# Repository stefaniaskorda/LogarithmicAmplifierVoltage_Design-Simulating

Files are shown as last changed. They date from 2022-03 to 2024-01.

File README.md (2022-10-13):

# microelectronics-and-packaging

Logarithmic Amplifier Project for the course Microelectronics&amp;Packaging

This project implemented for the course Microelectronics and Packaging at 7th semester in Electrical and Computer Engineering School of National Technical University of Athens and was graded 10/10.

## 0.Context: The circuit we have chosen is known as a logarithmic amplifier voltage, as the output voltage which produces, it is proportional to its neper logarithmic input voltage.
the circuit consists of a voltage source, a resistor, an opamp and a bjt transistor. In particular, we chose as an opamp the LM714, npn: 2N2222 and R=10KΩ. The schematic is shown below:

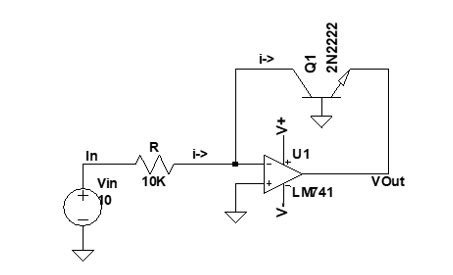
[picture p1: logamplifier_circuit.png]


## 1.Simulation of the circuit 
We ran a dc sweep simulation in LTspice to make sure our circuit is working properly. Spice doesn't have the LM741 model, so we had to import it. As we saw in the datasheet of LM714, it has a source voltage of +/-15v, so we put V+=15-1=14V and v-=-14v, as positive and negative supply voltage respectively. We set the dc sweep for Vin from 0.1 to 10v to see the VOUT curve as a function of the input voltage.

## 2.Designing PCB
In the specific part of the report, the schematic design of the circuit arrangement we have chosen, the voltage logarithmer, as well as the design of the board for the specific arrangement will be made through the EAGLE design program.

### The diagram using Eagle:
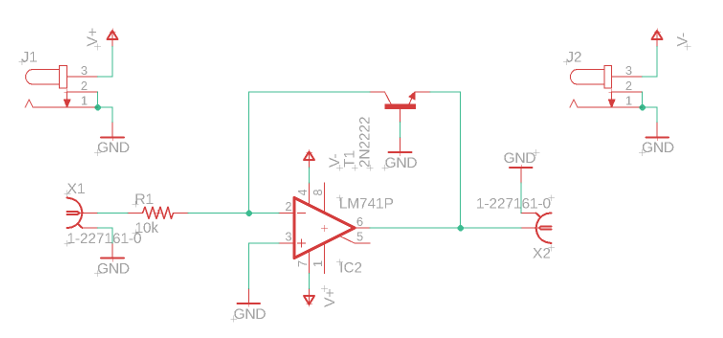
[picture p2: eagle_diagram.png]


### The final PCB design:
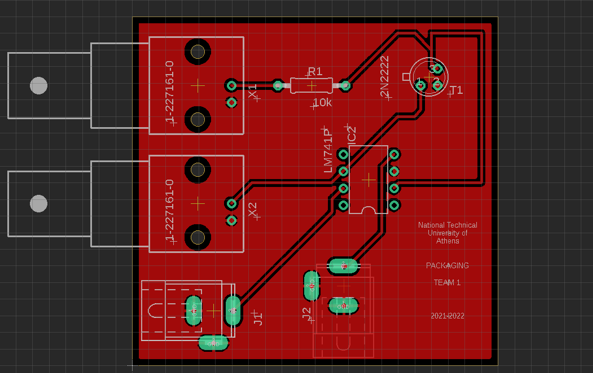
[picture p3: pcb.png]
## 3.Implementation of Heatsinks

## 4. Design of Heatsinks
Fusion360 was used as CAD program for the design of Heatsinks for the bjt (2n2222) and for the opamp (lm741).
Below are the designs:

### opamp lm741
* 1st Heatsink
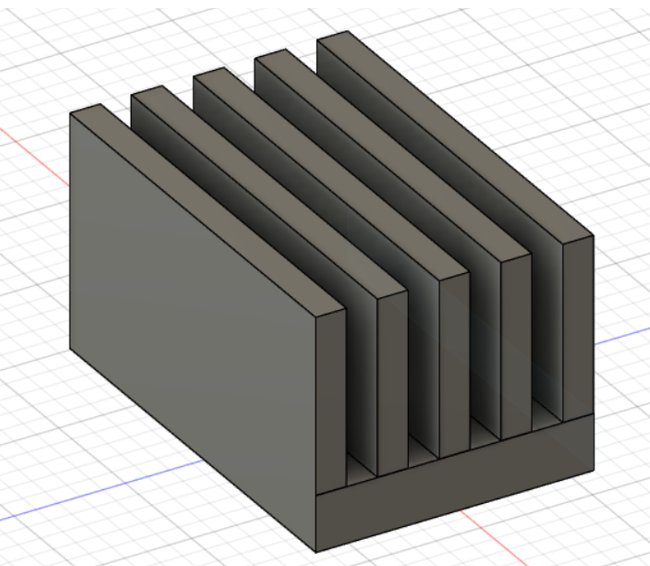
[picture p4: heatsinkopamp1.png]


* 2nd Heatsink
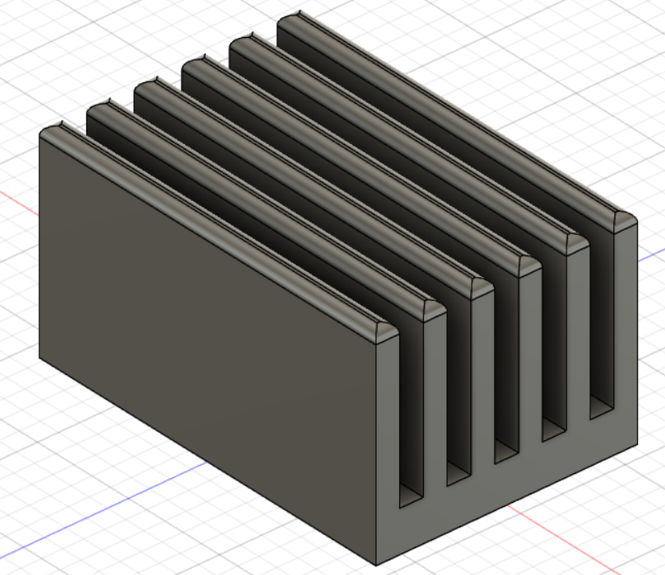
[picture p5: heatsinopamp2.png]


* 3rd Heatsink
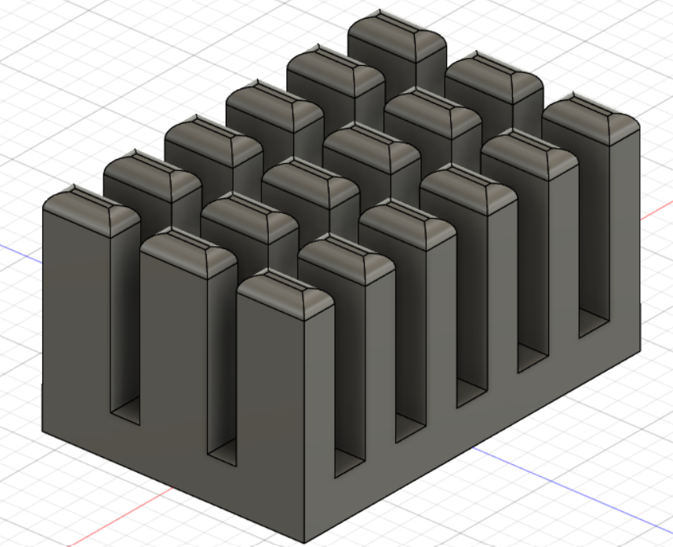
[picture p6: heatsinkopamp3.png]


* 4rth Heatsink
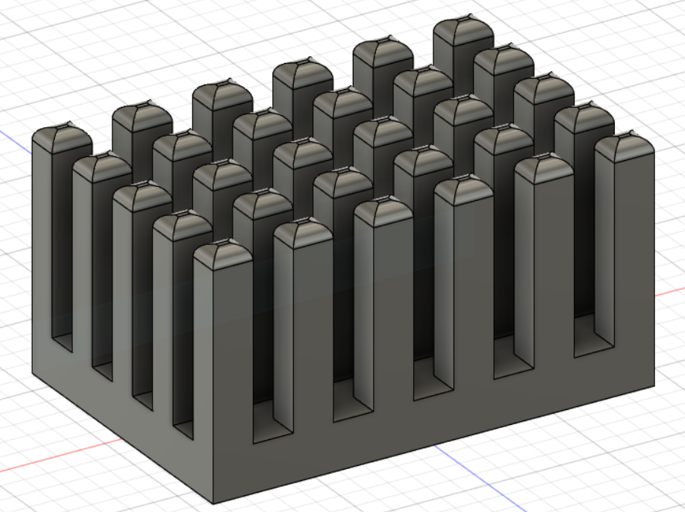
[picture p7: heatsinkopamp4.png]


### bjt 2n2222

* 1st Heatsink
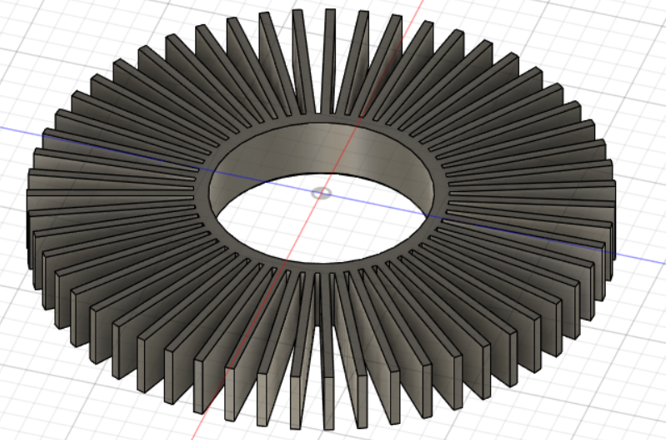
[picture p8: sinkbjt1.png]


* 2nd Heatsink
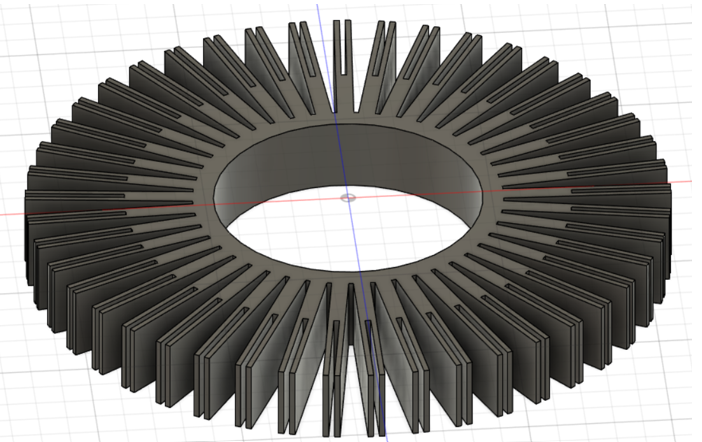
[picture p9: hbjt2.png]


## 5.Thermal Analysis

The thermal analysis of the board will be carried out to observe the ability of the heatsinks to fulfill their role, but also to make a comparison between them in terms of the cooling capacity of each one.

To be able to carry out the analysis we will use the online program SimScale.
Before we proceed with the simulations, the following fields in SimScale are required to be filled out.
More specifically, what needed to be filled in or changed in the simulation environment is included in the list below.
* Element Materials:
* LM741 (OPAMP): The OPAMP body (the polymer) is Epoxy. Its pins are made of lead.
* 2N2222 (NPN): The body of the bipolar is tin (Tin) . Its pins are made of lead.
* Heat sinks: All heat sinks are made of aluminum.

### opamp lm741
* 1st Heatsink
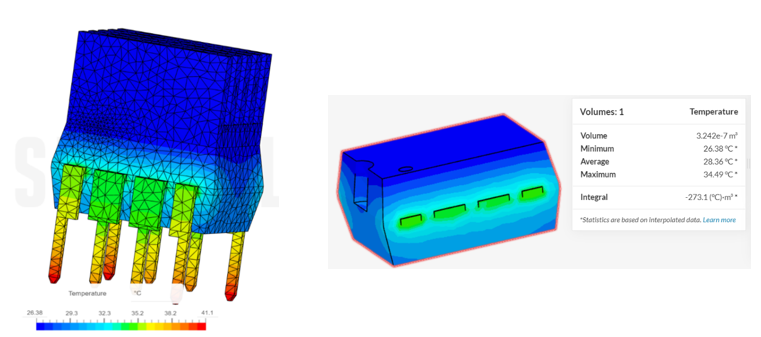
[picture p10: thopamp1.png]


* 2nd Heatsink
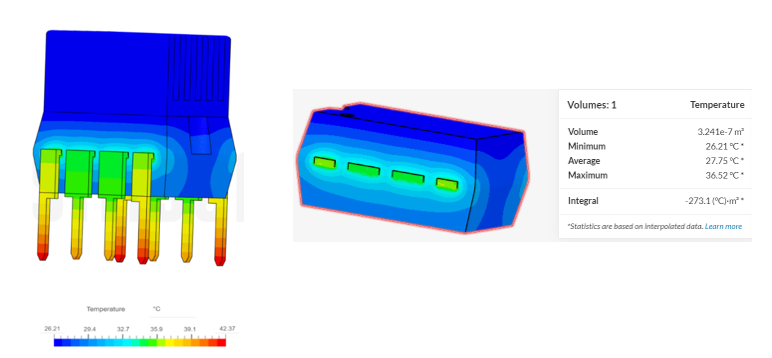
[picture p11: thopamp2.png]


* 3rd Heatsink
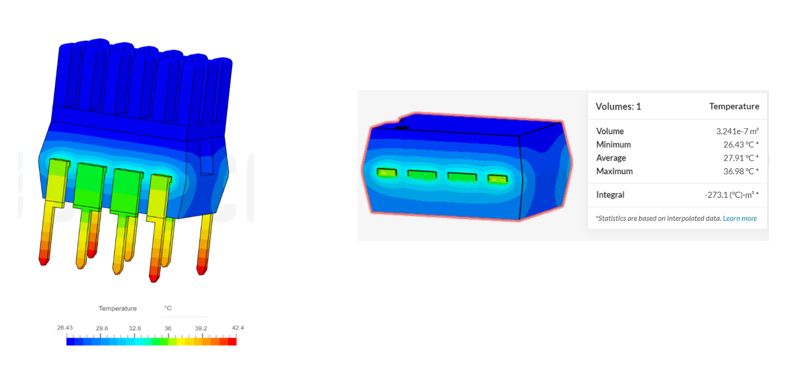
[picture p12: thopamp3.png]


* 4rth Heatsink
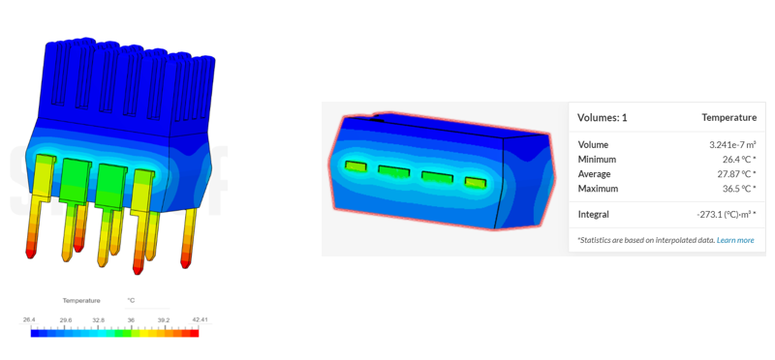
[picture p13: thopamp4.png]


### bjt 2n2222

* 1st Heatsink
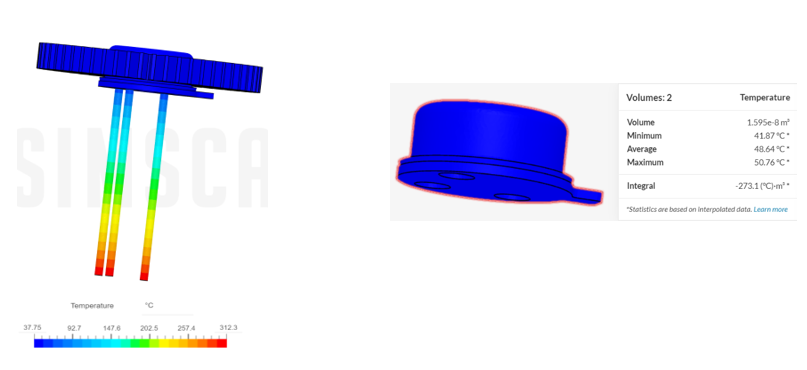
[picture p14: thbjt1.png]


* 2nd Heatsink
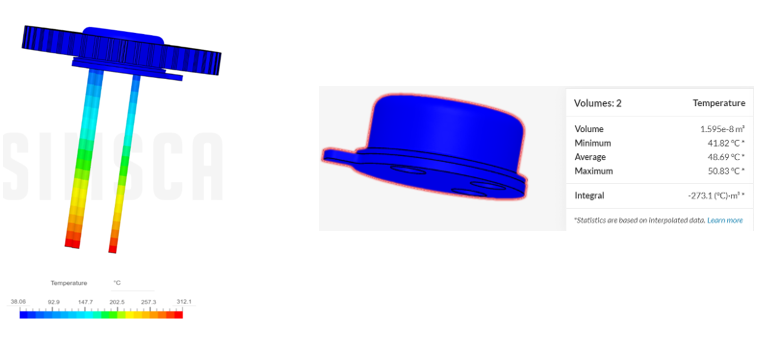
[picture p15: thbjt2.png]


## 6. Conclusion

For the opamp lm741 the 2nd Heatsink approoved as the best one and for the bjt 2n2222 the 1st one was the best as heatsinks.

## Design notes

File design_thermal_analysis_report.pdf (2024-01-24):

## ΕΘΝΙΚΟ ΜΕΤΣΟΒΙΟ ΠΟΛΥΤΕΧΝΕΙΟ

ΣΧΟΛΗ ΗΛΕΚΤΡΟΛΟΓΩΝ ΜΗΧΑΝΙΚΩΝ ΚΑΙ ΜΗΧΑΝΙΚΩΝ ΥΠΟΛΟΓΙΣΤΩΝ

ΚΑΤΕΥΘΥΝΣΗ ΗΛΕΚΤΡΟΝΙΚΗΣ ΚΑΙ ΣΥΣΤΗΜΑΤΩΝ

## Εξαμηνιαία Εργασία

## στο μάθημα «Μικροηλεκτρονική και Τεχνικές Συσκευασίας»

των φοιτητών

Λυμπεράκης Γεώργιος, Α.Μ: 03118881 Σκόρδα Στεφανία, Α.Μ: 03118852 Καγιάρα Νίκη, Α.Μ: 03118031 Ταξείδη Άρτεμις, Α.Μ:03116044

Διδάσκοντες: Χριστοφόρου Ευάγγελος

Αθήνα, Ιανουάριος 2022

Εισαγωγή – Περιγραφή Κυκλώματος

Το κύκλωμα που επιλέξαμε για τις προσομοιώσεις είναι γνωστό ως λογαριθμιστής τάσης, καθώς η τάση εξόδου που παράγει είναι ανάλογη του νεπέριου λογάριθμου της τάσης εισόδου του.

Το κύκλωμα αποτελείται από μια πηγή τάσης ,μια αντίσταση ,έναν opamp και ένα bjt transistor.Συγκεκριμένα επιλέξαμε ως opamp τον LM714, npn:2N2222 και R=10ΚΩ.Το σχηματικό φαίνεται παρακάτω:

Ακολουθεί η απόδειξη πως το κύκλωμα λειτουργεί ως λογαριθμιστής τάσης.

Ως γνωστόν ,σε έναν τελεστικό ενισχυτή ισχύει ),όπου Α το κέρδος του,V+,V- η τάση στον θετικό και τον αρνητικό ακροδέκτη εισόδου αντίστοιχα . Όμως στον ιδανικό opamp VOUT/A=0 η αντίσταση εισόδου του τελεστικού είναι και αυτή άπειρη, οπότε δεν περνάει ποτέ ρεύμα από μέσα του καθώς

Ι+=Ι-=0.

Οπότε το ρεύμα περνάει όλο από την αρνητική ανάδραση, συνεπώς από το bjt.Άρα ισχύει για το ρεύμα του συλλέκτη IC = I/R

Όμως το ρεύμα συλλέκτη ενός bjt δίνεται από τον τύπο: IC = IS ∗ (e

VCE
VT − 1),όπου ls
το ρεύμα κορεσμού και vt η θερμική τάση του bjt(σύμφωνα με το datasheet του 2Ν2222 :IS=1.16*10⁻¹⁴A και vt=25.28). Οπότε συνεπάγεται ότι: :

VIN
R

= IS ∗
(e

vce
vt − 1) ≅ IS ∗ e
VCE/vt καθώς e

vce/vt ≫ 1

vce = v− − vout = −vout ⇒ ln (

VIN
R

) = ln(IS) ∗ (−

vout
vt ) ⇒ vout = −vt ∗ ln(

vin
R ∗ IS)

Μια αναμενόμενη τιμή τάσης εξόδου σύμφωνα με τον παραπάνω τύπο είναι :για vin=10V:

Vout=0.025*ln(10/10^3*1.16*10^-14)=592.2mV

Στην συνέχεια εκτελέσαμε στο LTspice μια dc sweep προσομοίωση για να βεβαιωθούμε ότι το κύκλωμα μας λειτουργάει σωστά. Το spice δεν διαθέτει το μοντέλο του LM741,οποτε έπρεπε να το εισάγουμε εμείς. Όπως είδαμε στο datasheet του LM714,εχει τάση κόρου +/-15v,οπότε βάζουμε V+=15-1=14V και v-=-14v,ως θετική και αρνητική τάση τροφοδοσίας αντίστοιχα. Ορίσαμε το dc sweep για την Vin από 0.1 έως 10v για να δούμε την καμπύλη VOUT συναρτήσει της τάσης εισόδου .Παρακάτω φαίνεται το κύκλωμα έτοιμο για προσομοίωση.

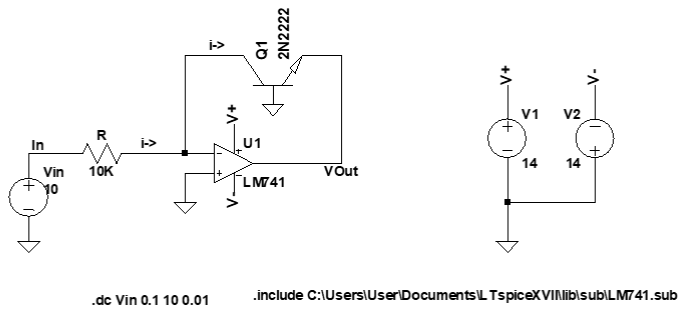
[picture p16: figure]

Παρακάτω φαίνεται η καμπύλη VOUT(VIN),η οποία, όπως φαίνεται, είναι όντως λογαριθμική και οι τιμές της βρίσκονται στην αναμενομένη τάξη μεγέθους.

Επίσης πήραμε το ρεύμα στην έξοδο του opamp:

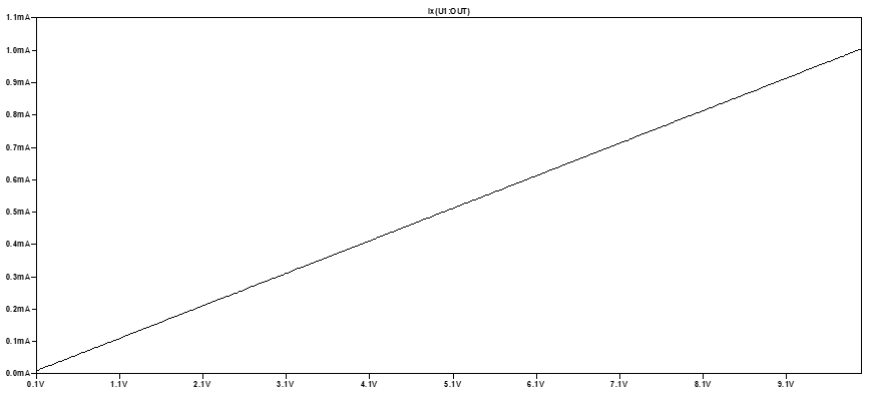
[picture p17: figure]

και έτσι υπολογίσαμε την ισχύ στην έξοδο του opamp P=IOUT*VOUT:

Παρατηρούμε ότι έχει αρνητικό πρόσημο καθώς ο ενισχυτής καταναλώνει ισχύ που αγγίζει μέχρι τα 700μwatt.

Τέλος υπολογίσαμε το ρεύμα εξόδου από το τρανζίστορ ,το οποίο, όπως ήταν αναμενόμενο έχει το ίδιο μέτρο με του opamp ,αλλά αντίθετο πρόσημο ,καθώς το ρεύμα στον opamp έχει φορά προς τα έξω, οπότε η ισχύς θα είναι θετική.

Σχεδίαση Πλακέτας Κυκλώματος (EAGLE)

Στο συγκεκριμένο μέρος της αναφοράς, θα γίνει η σχεδίαση του σχηματικού της κυκλωματικής διάταξης που επιλέξαμε, του λογαριθμιστή τάσης, καθώς και η σχεδίαση της πλακέτας για την συγκεκριμένη διάταξη μέσω του σχεδιαστικού προγράμματος EAGLE.

Το σχεδιαστικό πρόγραμμα EAGLE παρέχει στους χρήστες ένα σχετικά βατό τρόπο εκμάθησης και χρήση του layout editor και σχεδίασης της διάταξης, ενώ επιτρέπει επίσης στους χρήστες να υλοποιούν πιο σύνθετα σχέδια.

Το πρώτο βήμα για τη μετάβαση από μία προσομοίωση της διάταξης μέσω του LTspice, όπως έγινε προηγουμένως, είναι η αναδημιουργία του σχεδίου στο EAGLE προσθέτοντας τα ζητούμενα εξαρτήματα και συνδέοντάς τα στο schematic editor. Για να γίνει αυτό, το EAGLE παρέχει τη δυνατότητα αναζήτησης για τα components που ζητάμε.

Τα components που χρησιμοποιήθηκαν για την σχεδίαση του λογαριθμιστή τάσης είναι τα εξής:

DC Power Jack: SPC4077

Τροφοδοσία Κυκλώματος: V+,V-

Γείωση(GND):

Αντίσταση 10k: R-US_0207/10

OPAMP: LM741P

Τρανζίστορ BJT: 2N2222

Ομοαξονικό Καλώδιο(con-coax): 1-227161

Παρατίθεται το σχηματικό του λογαριθμικού ενισχυτή:

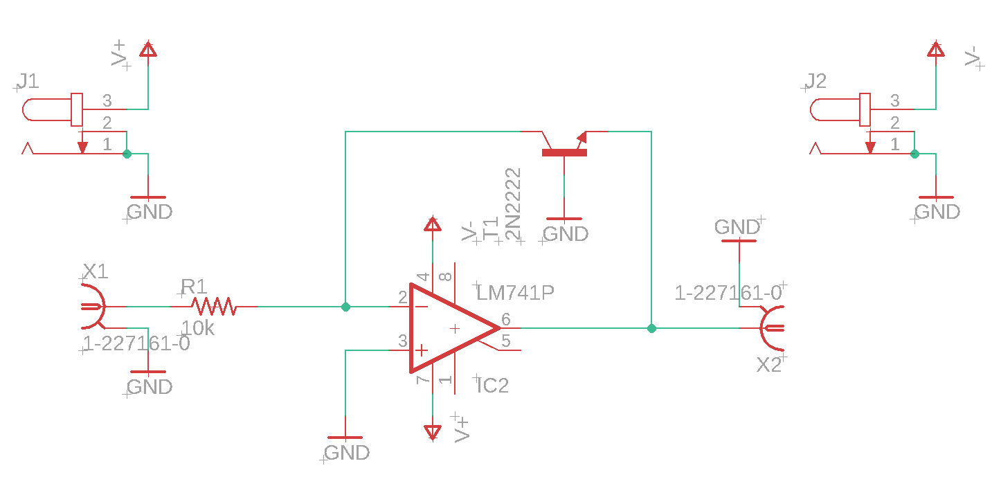
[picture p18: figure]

Πατώντας το εικονίδιο ERC, ελέχθηκε το κύκλωμα για τυχόν σφάλματα. Εφόσον δεν υπήρχαν σφάλματα, συνεχίζουμε στην κατασκευή της πλακέτας.

Πατώντας Generate/Switch to board, ξεκινάμε την
σχεδίαση και κατασκευή του PCB.

Έχοντας έτοιμο το Schematic, μεταφερόμαστε στο περιβάλλον board layout.

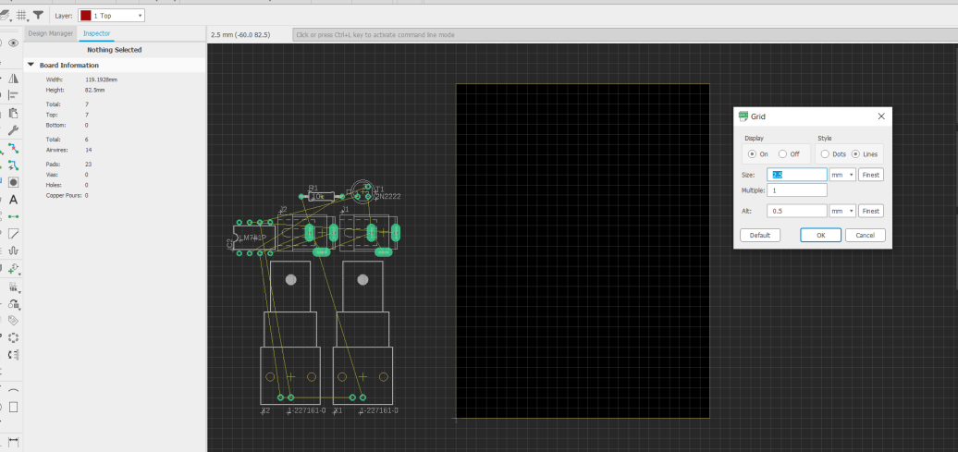
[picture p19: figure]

Στη συνέχεια, ορίζουμε τις διαστάσεις του grid για την διευκόλυνση της σχεδίασής μας.

Τοποθετούμε λοιπόν τα εξαρτήματα στον χώρο της πλακέτας με τέτοιο τρόπο ώστε να υπάρχει η ελάχιστη δυνατή αλληλοεπικάλυψη των Airwires.

Ορίζουμε στην συνέχεια το Ground plane της πλακέτας με όρθια γωνία, width&isolate : 40.64mil :

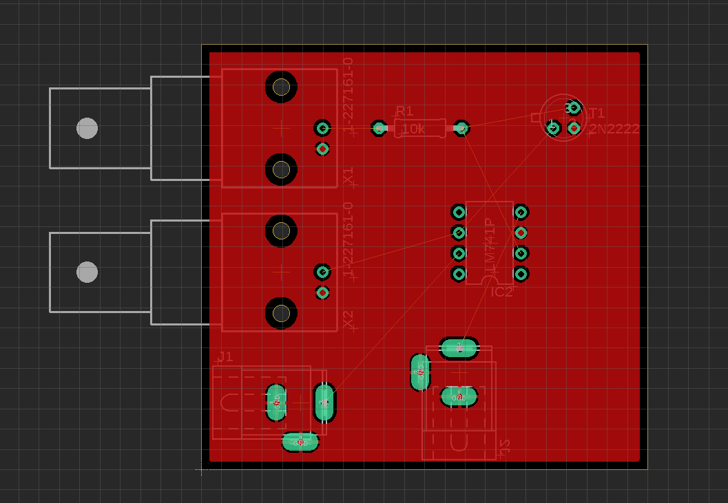
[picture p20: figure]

Έπειτα ορίζουμε τους αγώγιμους δρόμους με αμβλεία γωνία και width: 40.64mil :

Αφού ελέγξαμε ότι δεν υπάρχουν Airwires, πατήθηκε το πλήκτρο DRC για έλεγχο της πλακέτας. Με προσαρμογή των θέσεων των ονομάτων του κάθε εξαρτήματος, η τελική πλακέτα PCB είναι η εξής:

Και ως αρχείο tif:

Σχεδίαση και κατασκευή ψυκτρών (Fusion 360)

Σε πολλές ηλεκτρονικές εφαρμογές, η θερμοκρασία αποτελεί σημαντικό σχεδιαστικό παράγοντα. Οι απώλειες μεταγωγής (switching losses) και αγωγιμότητας (conduction losses) θερμαίνουν το πυρίτιο του στοιχείου πάνω από την μέγιστη επιτρεπτή θερμοκρασία ένωσης (Maximum Junction Temperature - Tjmax), και προκαλούν αποτυχία απόδοσης, βλάβη ή και καταστροφή της διάταξης.

Η διαχείριση του θερμικού φορτίου προσδιορίζεται στο στάδιο σχεδιασμού του PCB με σχεδίαση κατάλληλων ψυκτρών (ενεργών ή παθητικών), προσφέροντας δυνατότητα βελτιστοποίησης του συστήματος, μεγαλύτερη ευελιξία, περισσότερες επιλογές και περιορισμό των πιθανών αστοχιών μετά την ολοκλήρωση του σχεδιασμού. Στόχος της προσάρτησης ψυκτρών στα κρίσιμα στοιχεία της διάταξης είναι η μείωση της Tj έτσι ώστε να μην υπερβαίνει την Tjmax του στοιχείου.

Παράμετροι σχεδίασης ψύκτρας

Η σχεδίαση της ψύκτρας (σχήμα, υλικό κ.ο.κ.) βασίζεται στους τρόπους μετάδοσης θερμότητας (αγωγή, συναγωγή, θερμική ακτινοβολία) και τις παραμέτρους από τις οποίες εξαρτώνται. Πιο συγκεκριμένα:

- Μετάδοση της θερμότητας με αγωγή:

Σύμφωνα με τον Νόμο Fourier, η μεταφορά θερμότητας με αγωγή εκφράζει τη ροή θερμότητας Q από ένα σώμα στο άλλο μέσω επαφής.

Q =

kAc
t
- (T1 − T2)

Q: Θερμότητα (Watt)

k: Θερμική αγωγιμότητα θερμαινόμενου υλικού (W/m-℃)

Ac: Επιφάνεια επαφής (m²
)

T: Θερμοκρασία (C)

t: πάχος του υλικού (m)

Επομένως για μέγιστη μετάδοση θερμότητας από το στοιχείο ενδιαφέροντος στο εξωτερικό περιβάλλον η ψύκτρα πρέπει να έχει μεγάλη επιφάνεια επαφής με το στοιχείο (άρα η επιφάνεια επαφής πρέπει να είναι λεία), μικρό πάχος (στην επιφάνεια επαφής) και να αποτελείται από υλικό με υψηλή θερμική αγωγιμότητα (τόσο η ψύκτρα όσο και η πάστα κόλλησης της).

- Μετάδοση της θερμότητας με (ελεύθερη) μεταφορά (συναγωγή):

Μεταφορά θερμότητας στα υγρά και τα αέρια όπου ποσότητες κινούμενου ρευστού θερμαίνονται και μεταφέρονται σε ψυχρότερη περιοχή, όπου και προκαλούν την θέρμανσή της. Μπορεί να υπάρξει διάδοση μεταξύ στερεού και υγρού ή αέριου σώματος.

Q = ℎcAs

- (Ts − Ta)

hc: συντελεστής μεταφοράς (εξαρτάται από το ρευστό και την ταχύτητα του)

Αs: επιφάνεια επαφής με το ρευστό

Τs: θερμοκρασία επιφάνειας

Ta: θερμοκρασία ρευστού

Στην περίπτωση των ψυκτρών η συναγωγή είναι ροή αέρα (σε θερμοκρασία περιβάλλοντος χωρίς εξαναγκασμένη ροή/άγνωστη ταχύτητα) ανάμεσα στα “πτερύγια” (fins) που προκαλείται από δυνάμεις άνωσης λόγω διαφορετικών πυκνοτήτων, που προκαλούνται από τις διακυμάνσεις της θερμοκρασίας στο ρευστό. Επομένως ,από τα παραπάνω, τα πτερύγια πρέπει να είναι κάθετα ευθυγραμμισμένα και η μεταξύ τους απόσταση να είναι τυπικά μεγαλύτερη των 0.6mm ώστε να αυξάνεται η επιφάνεια επαφής ρευστού-ψύκτρας.

- Μετάδοση με θερμική ακτινοβολία:

Η θερμική ακτινοβολία διαδίδεται στο χώρο με την μορφή ηλεκτρομαγνητικών κυμάτων μεταξύ δύο επιφανειών. Από την εξίσωση Stefan-Boltzmann :

Q = εσAr

(Ts

4 − Ta

4
)

ℎr = εσ(Ts + Ta)(Ts

2 − Ta

2
)

ε: emissivity (χαρακτηριστικό υλικού)

Ar: επιφάνεια ακτινοβόλησης

Ts: θερμοκρασία επιφάνειας
σ = 5.67 10⁻⁸ Watt
m²K⁴

η σταθερά Stefan-Boltzmann

Ta: θερμοκρασία ρευστού

hr: συντελεστής μεταφοράς θερμικής ακτινοβολίας

Επομένως για μέγιστη μετάδοση θερμότητας από το στοιχείο ενδιαφέροντος στο εξωτερικό περιβάλλον η ψύκτρα πρέπει να διαθέτει μεγάλη ελεύθερη εκτιθέμενη επιφάνεια και να αποτελείται από υλικό με υψηλό emissivity.

Λαμβάνοντας υπόψη τους παραπάνω κανόνες για βέλτιστη σχεδίαση ψυκτρών και με χρήση του σχεδιαστικού προγράμματος Fusion 360, ακολουθεί η σχεδίαση και εφαρμογή ψυκτρών στα κρίσιμα στοιχεία της διάταξης (τελεστικός ενισχυτής, διπολικό τρανζίστορ).

Σχεδίαση ψυκτρών στο Fusion 360

Έχοντας σχεδιάσει το κύκλωμα και το PCB στο Eagle, όπως παρουσιάστηκε παραπάνω, λαμβάνεται το step αρχείο της διάταξης, από το οποίο με εισαγωγή στο Fusion 360 προκύπτει η η τρισδιάστατη αναπαράσταση της διάτρητης πλακέτας που σχεδιάστηκε (σχήμα 1).

Ακολουθεί αναλυτική περιγραφή της διαδικασίας σχεδίασης ψυκτρών για κάθε ένα από τα δύο στοιχεία.

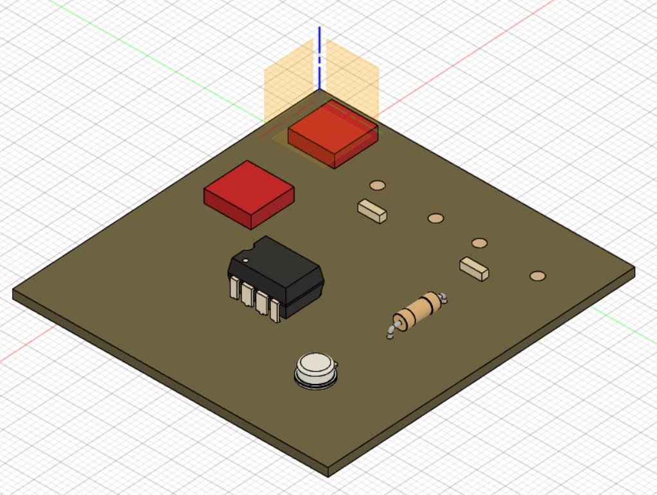
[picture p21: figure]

- Op Amp LM741

Σχήμα 1: Τρισδιάστατη αναπαράσταση PCB στο fusion 360

Από την τρισδιάστατη απεικόνιση του PCB απομονώνεται ο τελεστικός ενισχυτής και με το εργαλείο inspect μετρούνται οι βασικές διαστάσεις του LM741P, οι οποίες παρουσιάζονται στα παρακάτω σχήματα.

Σχήμα 2: Διαστασιολόγηση τελεστικού ενισχυτή

1

η Σχεδίαση:

Σε νέο project δημιουργείται sketch το οποίο επιλέγεται να είναι ορθογώνιο σχεδιασμένο με βάση το κέντρο του. Επειδή η ψύκτρα του op amp θα προσκολληθεί στην άνω βάση του (μεγάλη επιφάνεια επαφής με το στοιχείο - βέλτιστη επιλογή σύμφωνα με την ανάλυση που προηγήθηκε) επιλέγονται διαστάσεις ορθογωνίου 9.349 mm, 6.301 mm και
οριστικοποιείται η σχεδίαση (σχήμα 3).

Για την δημιουργία τρισδιάστατης βάσης, με δεξί κλικ πάνω στο sketch επιλέγεται το εργαλείο press pull. Ορίζεται ως πάχος 1.273 mm (επιλέχθηκε περίπου ως το ¼ του πάχους του LM741 – ικανοποιητική επιλογή δεδομένου ότι η ψύκτρα πρέπει να διαθέτει μικρό πάχος στην επιφάνεια επαφής του στοιχείου) στην θετική φορά του κάθετου στο επίπεδο άξονα και δημιουργείται νέο στερεό σώμα (σχήμα 4).

Δεδομένης της ανάλυσης των παραμέτρων σχεδίασης ψύκτρας που προηγήθηκε (πτερύγια κάθετα στην βάση - μεγάλη ελεύθερη επιφάνεια) δημιουργείται ορθογώνιο sketch στο άνω επίπεδο της βάσης με μήκος το μήκος της μεγάλης διάστασης της και πλάτος 0.7mm (προσάρτηση 5 όμοιων fins με ίσα μεταξύ τους διαστήματα → 6.301/9~0.7mm) και οριστικοποιείται η σχεδίαση (σχήμα 5).

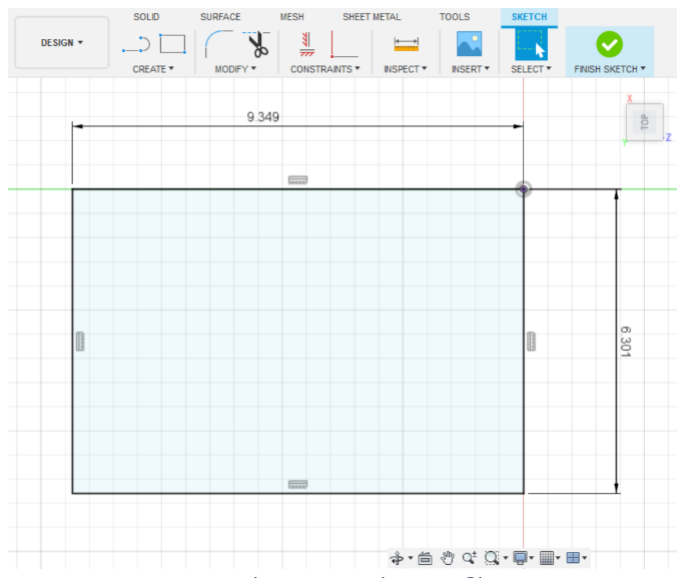
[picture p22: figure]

Σχήμα 3: 1ο Βήμα Σχεδίασης

Σχήμα 4: 2ο Βήμα Σχεδίασης

Σχήμα 5: 3ο Βήμα Σχεδίασης

Για δημιουργία τρισδιάστατου fin, με δεξί κλικ πάνω στο sketch επιλέγεται το εργαλείο press pull. Ορίζεται ως πάχος 4mm (επιλέχθηκε περίπου όσο του πάχους του LM741) στην θετική φορά του κάθετου στην βάση άξονα και δημιουργείται νέο στερεό σώμα (όχι joint ώστε να είναι δυνατή η επιλογή του ως ξεχωριστό σώμα- χρήσιμο στο επόμενο βήμα για προσθήκη των υπόλοιπων fins) (σχήμα 6).

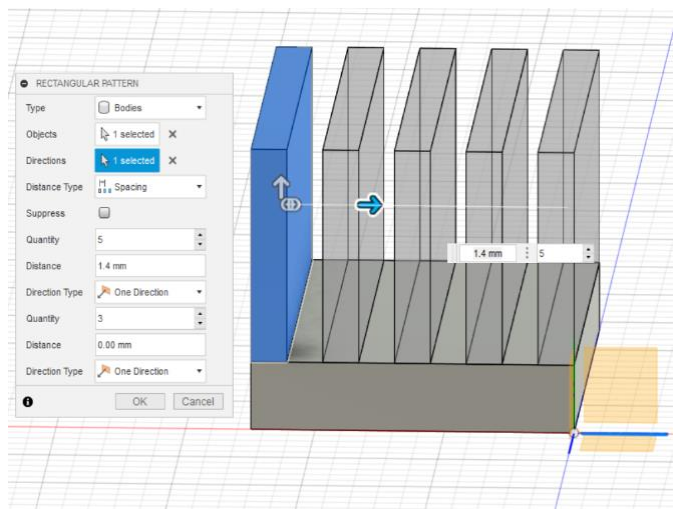
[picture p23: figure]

Για ταχύτερη δημιουργία των fins, από το μενού επιλέγεται create → pattern → rectangular pattern που επαναλαμβάνει το αντικείμενο της επιθυμίας μας. Για επιλογή όλου του πτερυγίου ορίζεται type → bodies ενώ ορίζονται ως άξονας επανάληψης ο x, ως τρόπος διάταξης των fins η μεταξύ τους απόσταση η οποία ισούται με 1.4mm (0.7 διάκενο + 0.7 από την αρχή του προηγούμενου fin) και αριθμός πτεριγίων στο 5 (σχήμα 7).

Το τελικό βήμα είναι η ενοποίηση των επιμέρους τμημάτων (fins, base της ψύκτρας). Από από το μενού επιλέγεται modify → combine, ορίζεται operation → join και διαλέγονται τα στοιχεία που θα ενοποιηθούν. Με αυτό τον τρόπο η ψύκτρα ορίζεται ως ενιαίο στερεό (σχήμα 8).

Σχήμα 6: 4ο Βήμα Σχεδίασης

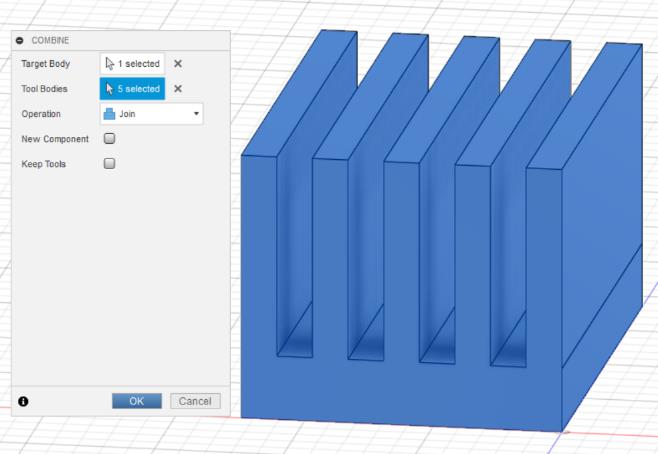
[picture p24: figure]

Σχήμα 8: 6ο Βήμα Σχεδίασης

Σχήμα 7: 5ο Βήμα Σχεδίασης

Ακολουθούν όψεις και τομές της 1ης ψύκτρας που σχεδιάστηκε.

Σχήμα 9: Τελικό αποτέσμα σχεδίασης 1ης ψύκτρας στο fusion 360

Σχήμα 10: Πρόσοψη ψύκτρας | Σχήμα 11: κάτοψη ψύκτρας

2

η Σχεδίαση:

Τα βήματα που περιγράφηκαν παραπάνω είναι κοινά και για τις 2 σχεδιάσεις, με μικρές διαφοροποιήσεις. Οπότε για λόγους συντομίας θα παρουσιαστούν μόνο οι διαφορές τους.

Έχοντας βάση πάχους 1mm

(βήματα 1-2) δημιουργούνται πτερύγια πλάτους 0.572 mm (προσάρτηση 6 όμοιων fins με μεταξύ τους διαστήματα 0.574 mm), μήκους 9.349mm (βήμα 3) και ύψους 4mm (βήμα 4).

(σχήμα 12)

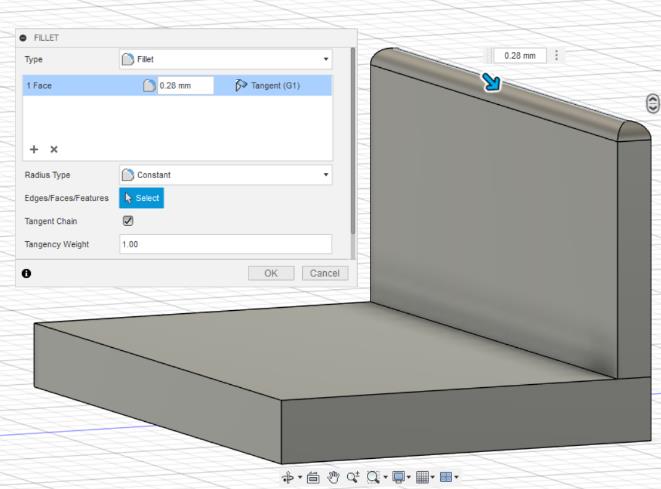
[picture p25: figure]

Δεδομένης | της | ανάλυσης | των
παραμέτρων σχεδίασης ψύκτρας που προηγήθηκε, στην δεύτερη περίπτωση “φιλετάρουμε” την κορυφή του fin ώστε να αυξηθεί η ελεύθερη επιφάνεια του. Από το μενού επιλέγεται modify → fillet, διαλέγουμε την άνω επιφάνεια του πτερυγίου και ορίζεται εφαπτόμενη γραμμή μήκους 0.28 mm βάση της οποίας θα γίνει η κυκλική τομή (σχήμα 13).

Ομοίως με την πρώτη σχεδίαση από το μενού επιλέγεται create → pattern → rectangular pattern που. Για επιλογή όλου του πτερυγίου ορίζεται type → bodies ενώ ορίζονται ως άξονας επανάληψης ο z, η διάταξη των fins να γίνεται με βάση την μεταξύ τους απόσταση η οποία ισούται με 1.4mm (0.574 mm διάκενο + 0.572 από την αρχή του προηγούμενου fin) και ως αριθμός πτερυγίων 6 (σχήμα 14). Στο
τέλος | γίνεται | η | ενοποίηση | των

επιμέρους τμημάτων της ψύκτρας (όπως στο βήμα 6 1ης σχεδίασης), προσδίδοντάς της ιδιότητες συμπαγούς στερεού εξαρτήματος.

Σχήμα 13: 5ο Βήμα Σχεδίασης

Σχήμα 14: 6οκαι 7ο Βήμα Σχεδίασης

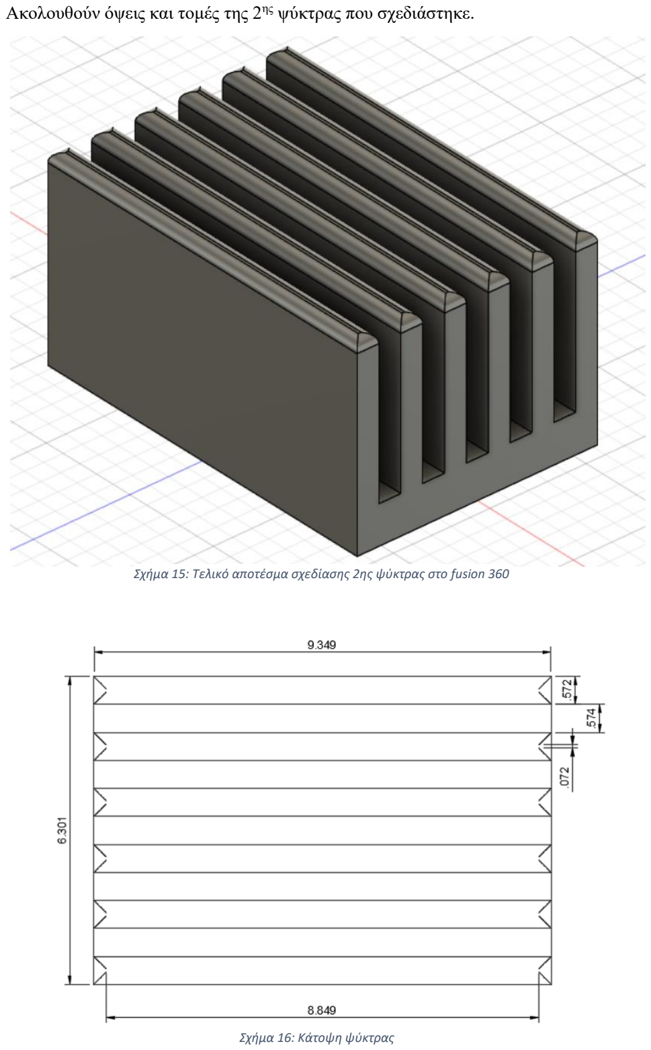
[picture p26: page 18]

Ακολουθούν όψεις και τομές της 2ης ψύκτρας που σχεδιάστηκε.

Σχήμα 15: Τελικό αποτέσμα σχεδίασης 2ης ψύκτρας στο fusion 360

Σχήμα 16: Κάτοψη ψύκτρας

3

η Σχεδίαση:

Στην τρίτη σχεδίαση, δημιουργείται ψύκτρα της οποίας τα πτερύγια δεν είναι ενιαία όπως στις προηγούμενες περιπτώσεις αλλά κάθε γραμμή αποτελείται από 3 όμοια fins πλάτους 0.849 mm, μήκους 1.633 mm, μέγιστου ύψους 4 mm και μεταξύ τους απόσταση 0.697 mm. Το μοτίβο αυτό επαναλαμβάνεται κατά μήκος της ψύκτρας σε συνολικά 6 γραμμές των 3 πτερυγίων. Σκοπός είναι η αύξηση της ελεύθερης επιφάνειάς τους και η διευκόλυνση της ροής αέρα για αυξημένη απαγωγή θερμότητας.

Έχοντας βάση πάχους 1mm

(βήματα 1,2) δημιουργούνται πτερύγια πλάτους 0.849 mm, μήκους 1.633 mm, και ύψους 4 mm (βήμα 4). Από το μενού επιλέγεται modify → fillet, διαλέγουμε την άνω επιφάνεια του πτερυγίου και ορίζεται εφαπτόμενη γραμμή μήκους 0.35 mm, βάση της οποίας γίνεται η κυκλική τομή (σχήμα 18).

Σχήμα 17: Πρόσοψη ψύκτρας

Σχήμα 18: 5ο Βήμα Σχεδίασης

Σχήμα 17: Πρόσοψη ψύκτρας

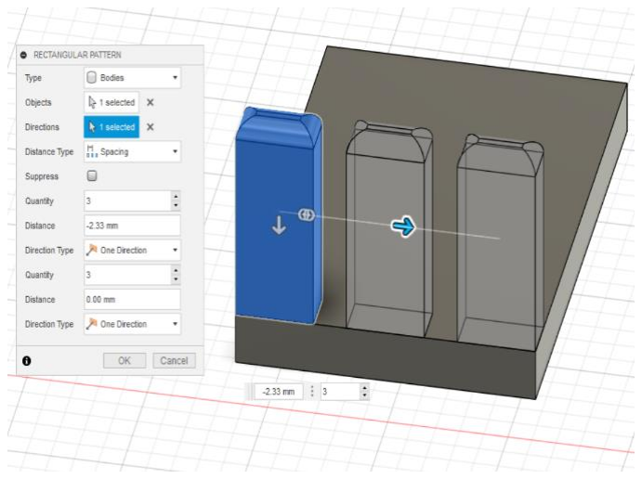
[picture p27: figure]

Για ταχύτερη δημιουργία των fins της 1ης γραμμής, από το μενού επιλέγεται create → pattern → rectangular pattern. Για επιλογή όλου του πτερυγίου ορίζεται type → bodies ενώ ορίζονται ως άξονας επανάληψης ο x, ως τρόπος διάταξης των fins η μεταξύ τους απόσταση η οποία ισούται με -2.33mm (0.633 διάκενο + 1.697 από την αρχή του προηγούμενου fin) και ως αριθμός πτερυγίων τίθεται 3 (σχήμα 19).

Ομοίως για την δημιουργία των 6 σειρών κατά μήκος της ψύκτρας από το μενού
επιλέγεται | create | → | pattern | →
rectangular pattern. Επιλέγονται τα 3 fin της 1ης γραμμής, ορίζονται ως άξονας επανάληψης ο x, ως τρόπος διάταξης των fin το μήκος που θα εκτείνονται, το οποίο ισούται με 8.5mm (9.349 μήκος ψύκτρας
- 0.849 από την αρχή του πρώτου πτερυγίου), και ως αριθμός επαναλήψεων τίθεται 6 (σχήμα 20). Στο τέλος γίνεται η ενοποίηση των επιμέρους τμημάτων της

ψύκτρας (όπως στο βήμα 6 1ης σχεδίασης), προσδίδοντάς της ιδιότητες συμπαγούς στερεού εξαρτήματος.

Ακολουθούν όψεις και τομές της 3ης ψύκτρας που σχεδιάστηκε.

Σχήμα 19: 6ο Βήμα Σχεδίασης

Σχήμα 20: 7ο Βήμα Σχεδίασης

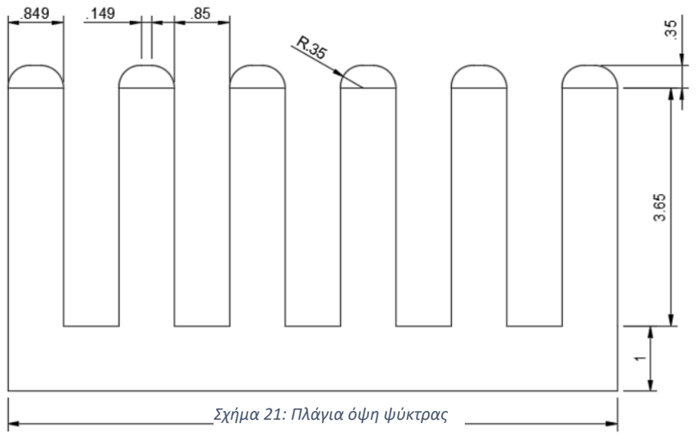
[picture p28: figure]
Σχήμα 21: Πλάγια όψη ψύκτρας

Σχήμα 22: Κάτοψη ψύκτρας

Σχήμα 23: Πρόσοψη ψύκτρας

4

η Σχεδίαση:

Στην τέταρτη σχεδίαση, δημιουργείται ψύκτρα όπως στην 3η με την διαφορά ότι κάθε γραμμή αποτελείται από 5 όμοια fins πλάτους 0.849 mm, μήκους 0.7 mm, μέγιστου ύψους 4 mm και μεταξύ τους απόσταση 0.7 mm. Το μοτίβο αυτό επαναλαμβάνεται και πάλι κατά μήκος της ψύκτρας σε συνολικά 6 γραμμές των 5 πτερυγίων. Σκοπός είναι η περεταίρω αύξηση της ελεύθερης επιφάνειάς τους και η ακόμα μεγαλύτερη αύξηση απαγωγής θερμότητας.

Έχοντας βάση πάχους 1mm

(βήματα 1,2) δημιουργούνται πτερύγια πλάτους 0.849 mm, μήκους 0.7 mm, και ύψους 4 mm (βήμα 4). Από το μενού επιλέγεται modify → fillet, διαλέγουμε την άνω επιφάνεια του πτερυγίου και ορίζεται εφαπτόμενη γραμμή μήκους 0.3 mm, βάση της οποίας γίνεται η κυκλική τομή (σχήμα 25).

Σχήμα 24: Τελικό αποτέσμα σχεδίασης 3ης ψύκτρας στο fusion 360

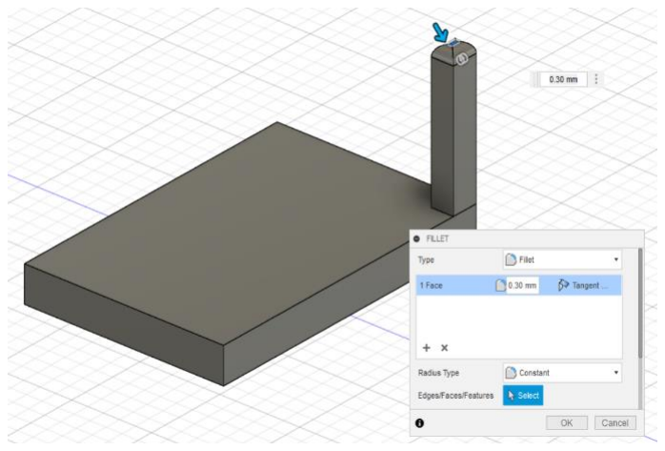
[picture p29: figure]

Σχήμα 25: 5ο Βήμα Σχεδίασης

Για ταχύτερη δημιουργία των fins της 1ης γραμμής, από το μενού επιλέγεται create → pattern → rectangular pattern. Για επιλογή όλου του πτερυγίου ορίζεται type → bodies ενώ ορίζονται ως άξονας επανάληψης ο x, ως τρόπος διάταξης των fins η μεταξύ τους απόσταση η οποία ισούται με -1.4mm (0.7 διάκενο + 0.7 από την αρχή του προηγούμενου fin) και ως αριθμός πτερυγίων τίθεται 5 (σχήμα 26).

Ομοίως για την δημιουργία των 6 σειρών κατά μήκος της ψύκτρας από το μενού επιλέγεται create → pattern → rectangular pattern. Επιλέγονται τα 5 fin της 1ης
γραμμής, | ορίζονται | ως | άξονας
επανάληψης ο x, ως τρόπος διάταξης των fin το μήκος που θα εκτίνονται, το οποίο ισούται με 8.5mm (9.349 μήκος ψύκτρας -
0.849 | από | την | αρχή | του | πρώτου
πτερυγίου), και ως αριθμός επαναλήψεων

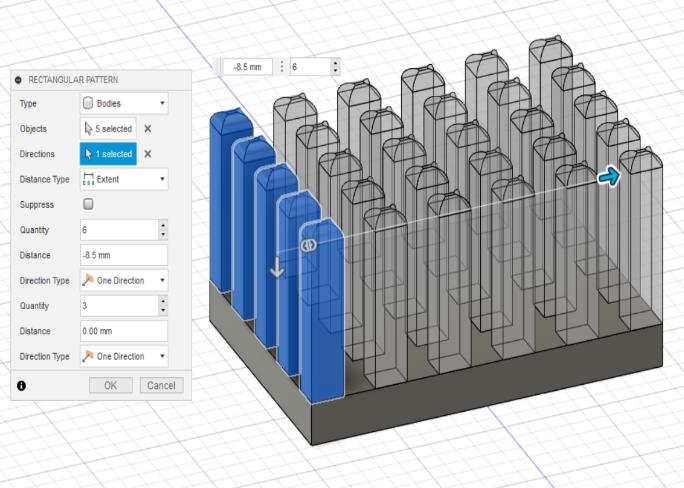
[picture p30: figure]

τίθεται 6 (σχήμα 27). Στο τέλος γίνεται η ενοποίηση των επιμέρους τμημάτων της ψύκτρας (όπως στο βήμα 6 1ης σχεδίασης), προσδίδοντάς της ιδιότητες συμπαγούς στερεού εξαρτήματος.

Ακολουθούν όψεις και τομές της 4ης ψύκτρας που σχεδιάστηκε.

Σχήμα 26: 6ο Βήμα Σχεδίασης

Σχήμα 27: 7ο Βήμα Σχεδίασης

Σχήμα 28: Πλάγια όψη ψύκτρας

Σχήμα 29: Κάτοψη ψύκτρας

Σχήμα 30: Πρόσοψη ψύκτρας

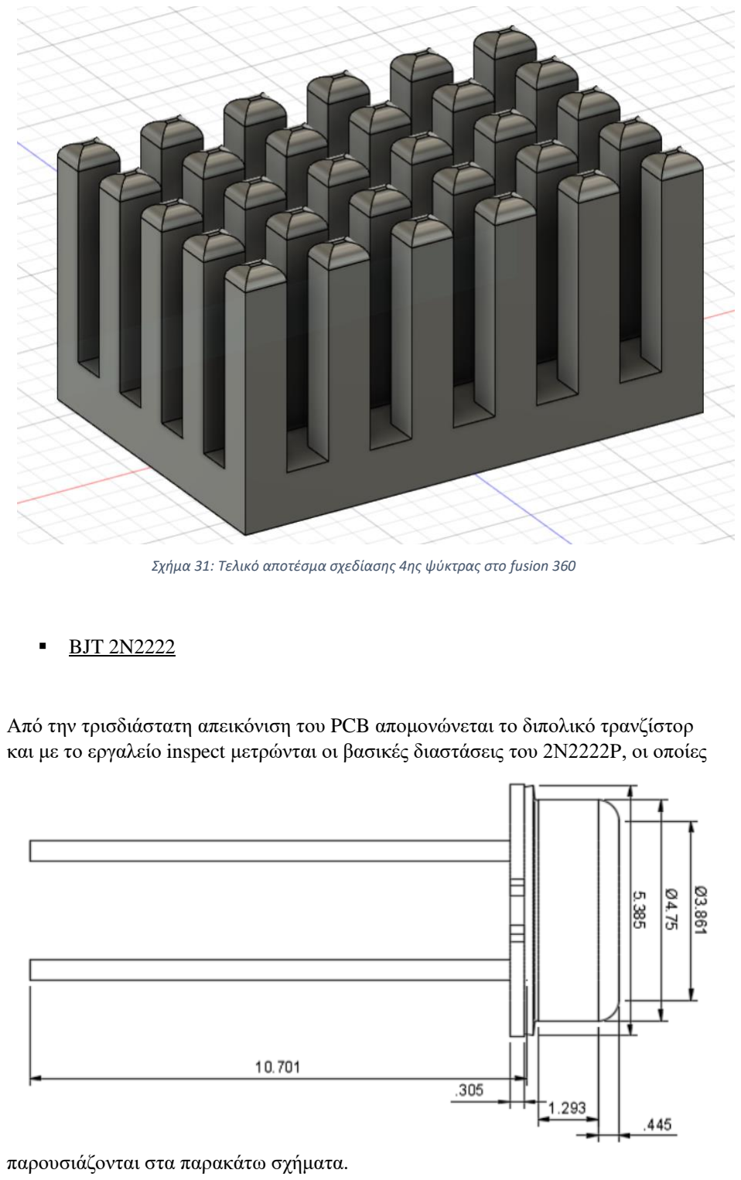
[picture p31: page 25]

- BJT 2N2222

Από την τρισδιάστατη απεικόνιση του PCB απομονώνεται το διπολικό τρανζίστορ και με το εργαλείο inspect μετρώνται οι βασικές διαστάσεις του 2Ν2222P, οι οποίες

παρουσιάζονται στα παρακάτω σχήματα.

Σχήμα 31: Τελικό αποτέσμα σχεδίασης 4ης ψύκτρας στο fusion 360

1

η Σχεδίαση:

Σε νέο project δημιουργείται sketch → κυκλικός δίσκος. Επειδή η ψύκτρα bjt θα προσαρτηθεί περιμετρικά στην παράπλευρη επιφάνεια διαμέτρου 4.75 mm (μεγάλη επιφάνεια επαφής με το
στοιχείο) | επιλέγεται | διάμετρος
5.385mm (πάχος ψύκτρας= 5.385 – 4.75 διάμετρος διπολικού= 0,635mm / ικανοποιητική επιλογή δεδομένου ότι η ψύκτρα πρέπει να διαθέτει μικρό πάχος στην επιφάνεια επαφής του στοιχείου)
και | οριστικοποιείται | η | σχεδίαση
(σχήμα 33).

Σχήμα 32: Διαστασιολόγηση BJT 2N2222

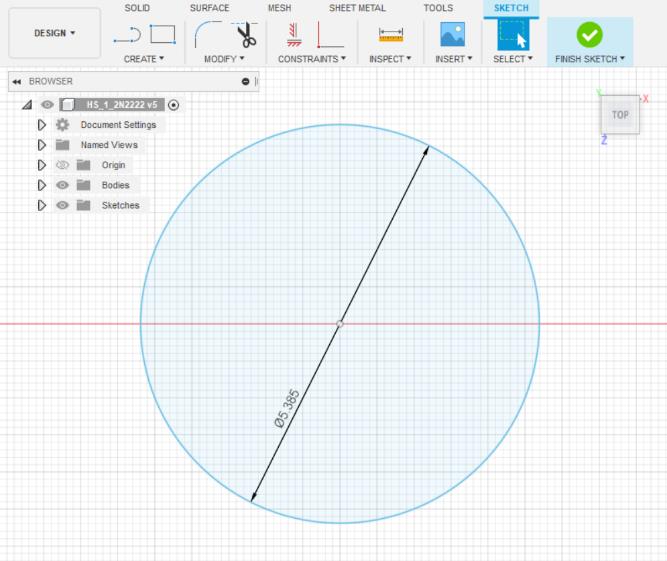
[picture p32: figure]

Σχήμα 33: 1ο Βήμα Σχεδίασης

Για | την | απόκτηση | τρισδιάστατης
υπόστασης, με δεξί κλικ πάνω στο sketch επιλέγεται το εργαλείο press pull. Ορίζεται ως πάχος 1.293 mm (όσο και το ύψος της παράπλευρης επιφάνειας που θα προσαρτηθεί) στην θετική φορά του
κάθετου | στο | επίπεδο | άξονα | και
δημιουργείται νέο στερεό σώμα (σχήμα 34).

Η ολοκλήρωση της βάσης της ψύκτρας απαιτεί την δημιουργία οπής στο συμπαγές στερεό σώμα που έχει σχεδιαστεί. Για τον σκοπό αυτό, σε πρώτο στάδιο, δημιουργείται sketch → κυκλικός δίσκος, ομόκεντρος με την κυκλική βάση και πάνω στο επίπεδό της με διάμετρο 4.75 mm, όση και η διάμετρος του διπολικού τρανζίστορ
και | οριστικοποιείται | η | σχεδίαση
(σχήμα 35).
Σε | δεύτερο | στάδιο, | για | την
δημιουργία οπής στο στερεό, με δεξί κλικ πάνω στο sketch επιλέγεται το εργαλείο press pull. Ορίζεται ως πάχος 1.293 mm (ώστε να διαπεράσει το στερεό) στην αρνητική φορά του κάθετου στο επίπεδο άξονα και επιλέγεται ως διεργασία που θα
πραγματοποιηθεί | “cut” | που | θα
αφαιρέσει το επιθυμητό | τμήμα
(σχήμα 36).

Σχήμα 34: 2ο Βήμα Σχεδίασης

Σχήμα 35: 3ο Βήμα Σχεδίασης

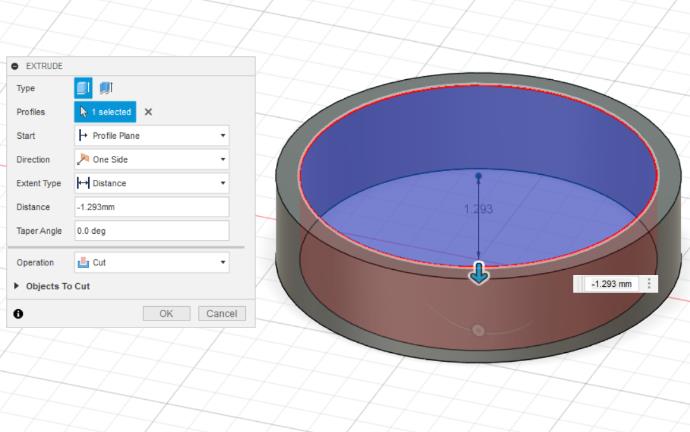
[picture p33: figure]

Σχήμα 36: 4ο Βήμα Σχεδίασης

Δεδομένης | της | ανάλυσης | των
παραμέτρων σχεδίασης ψύκτρας που προηγήθηκε (πτερύγια κάθετα στην βάση - μεγάλη ελεύθερη επιφάνεια) δημιουργείται ορθογώνιο sketch στο πλάγιο επίπεδο της βάσης με μήκος 3.5mm (επιλέχθηκε ώστε σε άθροισμα με το πάχος της βάσης να μην ξεπερνά
την | διάμετρο | του | διπολικού
τρανζίστορ) και πλάτος 1.293 mm, όσο
και | το | ύψος | της | βάσης, | και
οριστικοποιείται η σχεδίαση (σχήμα 37).

Για δημιουργία τρισδιάστατου fin, με δεξί κλικ πάνω στο sketch επιλέγεται το εργαλείο press pull. Ορίζεται ως πάχος 0.2mm στην θετική φορά του κάθετου στην βάση άξονα και δημιουργείται νέο στερεό σώμα (όχι joint ώστε να είναι δυνατή η επιλογή του ως ξεχωριστό σώμα- χρήσιμο στο επόμενο βήμα για προσθήκη των υπόλοιπων fins) (σχήμα 38).

Για ταχύτερη δημιουργία των fins, από το μενού επιλέγεται create → pattern → circular pattern. Για επιλογή όλου του πτερυγίου ορίζεται type → bodies ενώ ορίζονται ως άξονας επανάληψης ο z και ως αριθμός πτερυγίων 55 (ο αριθμός πτερυγίων επιλέχθηκε έτσι ώστε οι μεταξύ τους αποστάσεις να είναι
αρκετά | μεγάλες | ώστε | να | μην
επηρεάζονται από μετάδοση θερμικής ακτινοβολίας) (σχήμα 39).

Σχήμα 37: 5ο Βήμα Σχεδίασης

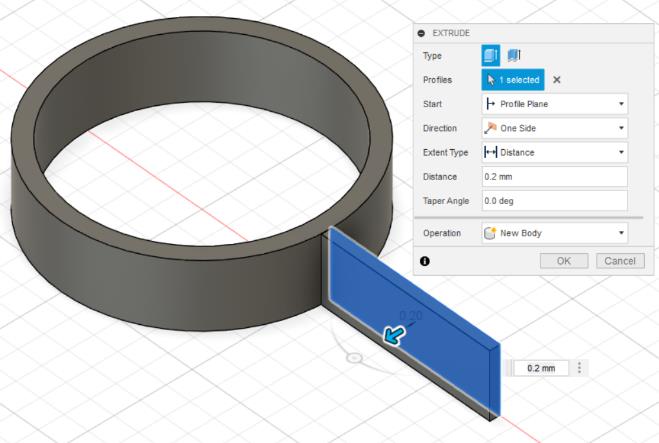
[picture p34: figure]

Σχήμα 38: 6ο Βήμα Σχεδίασης

Σχήμα 39: 7ο Βήμα Σχεδίασης

Το τελικό βήμα είναι η ενοποίηση των
επιμέρους | τμημάτων | (fins, | base | της
ψύκτρας). Από από το μενού επιλέγεται modify → combine, ορίζεται operation→ join και διαλέγονται τα στοιχεία που θα ενοποιηθούν. Με αυτό τον τρόπο η ψύκτρα ορίζεται ως ενιαίο στερεό

(σχήμα 40).

Ακολουθούν όψεις και τομές της 1ης ψύκτρας που σχεδιάστηκε.

Σχήμα 39: 7ο Βήμα Σχεδίασης

Σχήμα 40: 8ο Βήμα Σχεδίασης

Σχήμα 41: Πρόσοψη ψύκτρας

Σχήμα 42: Κάτοψη ψύκτρας

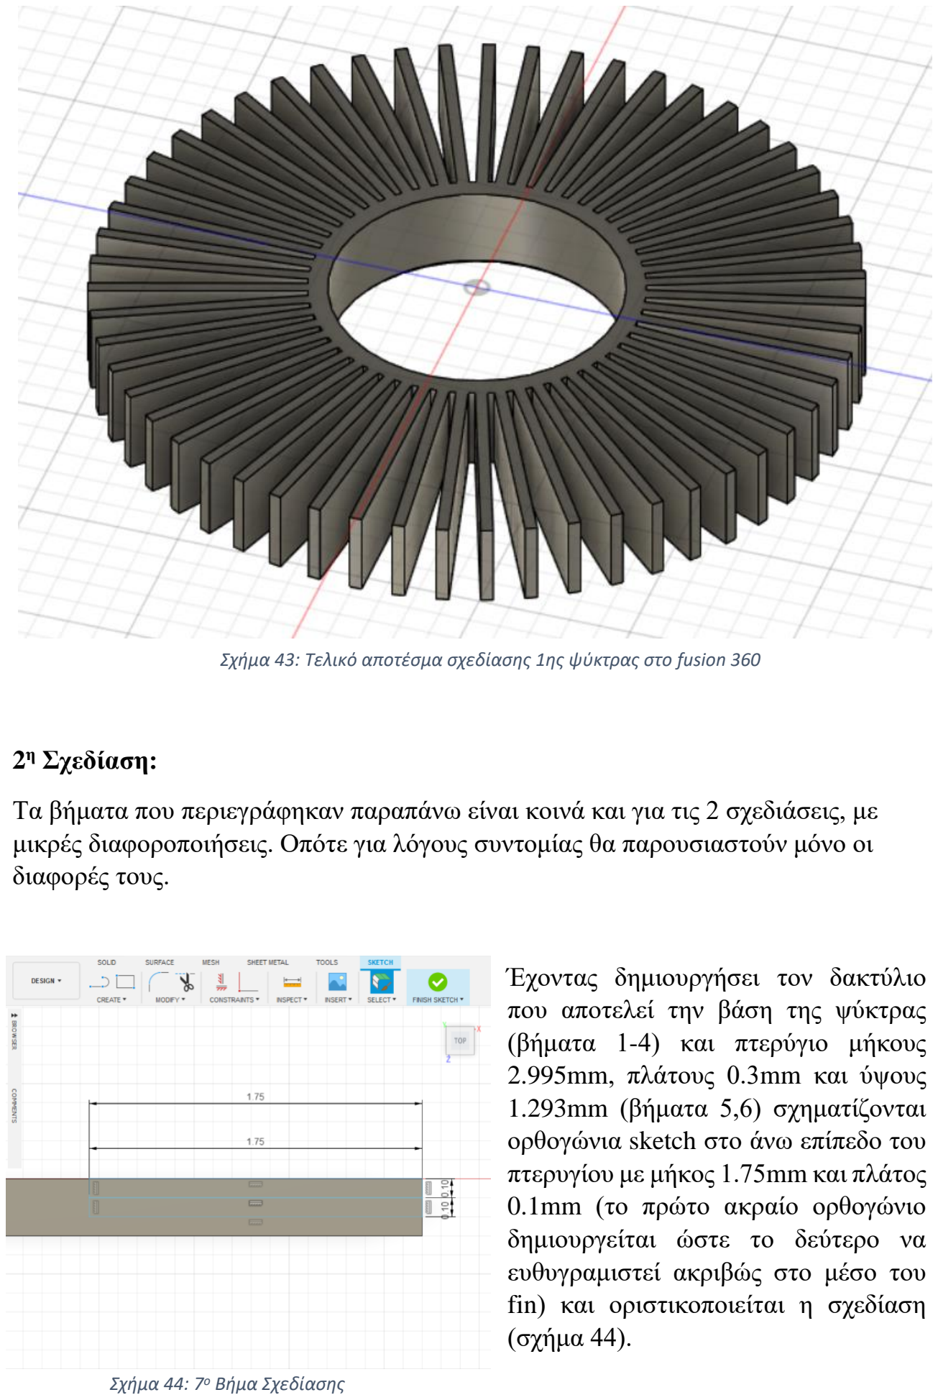
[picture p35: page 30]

2

η Σχεδίαση:

Τα βήματα που περιεγράφηκαν παραπάνω είναι κοινά και για τις 2 σχεδιάσεις, με μικρές διαφοροποιήσεις. Οπότε για λόγους συντομίας θα παρουσιαστούν μόνο οι διαφορές τους.

Έχοντας δημιουργήσει τον δακτύλιο που αποτελεί την βάση της ψύκτρας (βήματα 1-4) και πτερύγιο μήκους 2.995mm, πλάτους 0.3mm και ύψους 1.293mm (βήματα 5,6) σχηματίζονται ορθογώνια sketch στο άνω επίπεδο του πτερυγίου με μήκος 1.75mm και πλάτος 0.1mm (το πρώτο ακραίο ορθογώνιο δημιουργείται ώστε το δεύτερο να ευθυγραμιστεί ακριβώς στο μέσο του fin) και οριστικοποιείται η σχεδίαση (σχήμα 44).

Σχήμα 43: Τελικό αποτέσμα σχεδίασης 1ης ψύκτρας στο fusion 360

Σχήμα 44: 7ο Βήμα Σχεδίασης

Με δεξί κλικ πάνω στο 2ο
sketch
επιλέγεται το εργαλείο press pull. Ορίζεται ως πάχος 1.293 mm (ώστε να διαπεράσει το στερεό) στην αρνητική φορά του κάθετου στο επίπεδο άξονα και επιλέγεται ως διεργασία που θα
πραγματοποιηθεί | “cut” | που | θα
αφαιρέσει το επιθυμητό τμήμα (σχήμα 36). Έτσι η άκρη του fin διαχωρίζεται σε 2 ελάσματα πάχους 0.1mm έκαστο.

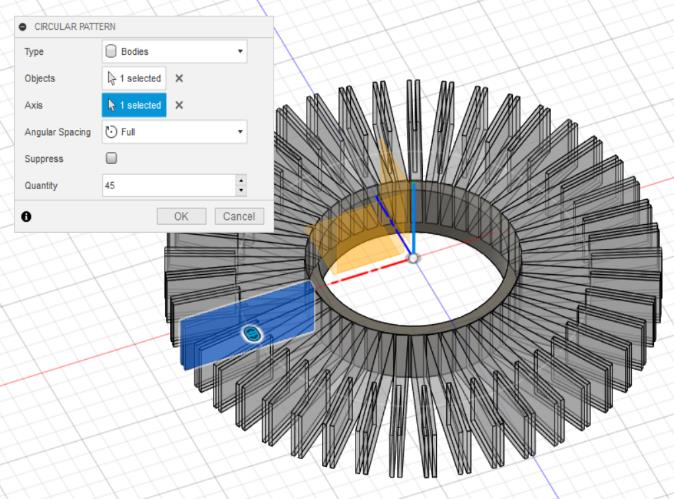
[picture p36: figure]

Για ταχύτερη δημιουργία των fins, από το μενού επιλέγεται create → pattern → circular pattern. Για επιλογή όλου του πτερυγίου ορίζεται type → bodies ενώ ορίζονται ως άξονας επανάληψης ο z και ως αριθμός πτερυγίων 45. Στο τέλος γίνεται η ενοποίηση των επιμέρους τμημάτων της ψύκτρας (όπως στο βήμα 8 1ης σχεδίασης για το 2N2222), προσδίδοντάς της ιδιότητες
συμπαγούς | στερεού | εξαρτήματος.
(σχήμα 46).

Aκολουθούν όψεις και τομές της 2ης ψύκτρας που σχεδιάστηκε.

Σχήμα 45: 8ο Βήμα Σχεδίασης

Σχήμα 46: 9ο Βήμα Σχεδίασης

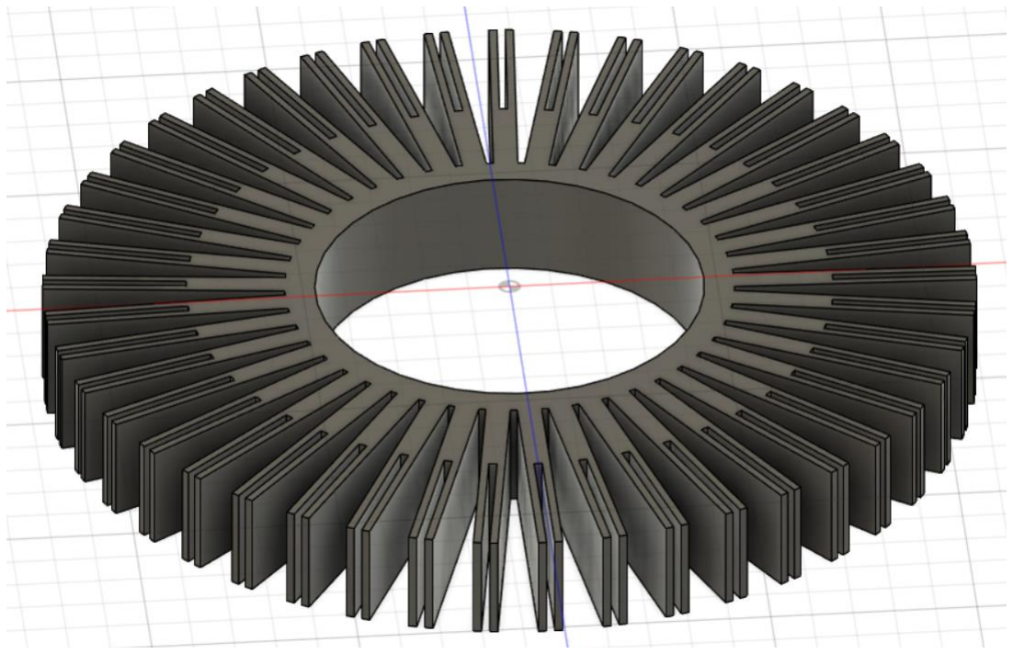
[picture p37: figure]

Σχήμα 47: Τελικό αποτέσμα σχεδίασης 2ης ψύκτρας στο fusion 360

Παρατηρήσεις

1. Για τις ψύκτρες του τελεστικού ενισχυτή LM741P:
- Αναμένουμε ότι όσο αυξάνεται η ελεύθερη επιφάνεια των πτερυγίων η αποτελεσματικότητα της ψύκτρας θα αυξάνεται. Επομένως στην θερμική ανάλυση στο simscale, που παρουσιάζεται στην επόμενη ενότητα, αναμένουμε να δούμε την θερμοκρασία του σώματος του τελεστικού ενισχυτή να μειώνεται

Σχήμα 49: Πρόσοψη ψύκτρας

Σχήμα 48: Κάτοψη ψύκτρας καθώς δοκιμάζουμε τις ψύκτρες με την εξής σειρά: ψύκτρα 1η → ψύκτρα 2η → ψύκτρα 3η → ψύκτρα 4η
- Η επιφάνεια επαφής των ψυκτρών με τον τελεστικό ενισχυτή είναι ίδια για όλες τις σχεδιάσεις. Ωστόσο μεταβάλλεται το πάχος της βάσης της ψύκτρας, καθώς στην 1η σχεδίαση είναι μεγαλύτερο από τις υπόλοιπες, οπότε αναμένεται και μείωση της αποτελεσματικότητας της έναντι των άλλων.
- Στις σχεδιάσεις 3,4 όπου τα πτερύγια είναι διαχωρισμένα τόσο κατά πλάτος όσο και κατά μήκος της βάσης της ψύκτρας διευκολύνεται η ελεύθερη ροή αέρα άρα απάγουν μεγαλύτερα ποσά θερμικής ενέργειας σε σύγκριση με τις σχεδιάσεις 1,2.
2. Για τις ψύκτρες του διπολικού τρανζίστορ 2Ν2222Ρ:
- Ομοίως με την περίπτωση του τελεστικού ενισχυτή, η αύξηση της ελεύθερης επιφάνειας των πτερυγίων προκαλεί αύξηση της αποτελεσματικότητα της ψύκτρας. Επομένως αναμένουμε η 1η ψύκτρα να είναι αποτελεσματικότερη από την 2η
- Στην σχεδίαση 2, το διάκενο ανάμεσα στα ελάσματα είναι πολύ μικρό (0.1mm) με αποτέλεσμα να αλληλεπιδρούν μεταξύ τους θερμικά (μεταφορά θερμικής ακτινοβολίας μεταξύ τους). Οπότε μειώνεται η αποδοτικότητά της.
3. Όπως περιεγράφηκε προηγουμένως για τις παραμέτρους σχεδίασης ψύκτρας, το υλικό από το οποίο είναι κατασκευασμένη πρέπει να έχει υψηλή θερμική αγωγιμότητα και υψηλό emissivity. Από τον πίνακα που ακολουθεί συμπεραίνουμε ότι το πιο ικανοποιητικό υλικό είναι το αλουμίνιο τόσο γιατί ικανοποιεί και τις δύο παραπάνω προδιαγραφές, όσο και των υπόλοιπων μηχανικών ιδιοτήτων του (χαμηλό βάρος, εξαιρετική αντοχή, υψηλό σημείο τήξης).
Material | Thermal Conductivity ( W/(mK)) | Emissivity
Silica Glass (https://en.wikipedia.org/wiki/Glass#Silicate_glass) | 1.38 | 0.92
Aluminium, anodized (https://en.wikipedia.org/wiki/Anodized) | 164 - 240 | 0.9
Aluminium, polished | | 0.04
Aluminium, extruded | | 0.06
Copper, oxidized | 69 - 76 | 0.78
Copper, polished | | 0.03
Copper, machined | | 0.07
Transition metal (https://en.wikipedia.org/wiki/Transition_metal) Disilicides (https://en.wikipedia.org/wiki/Disilicide) | 186 - 550 | 0.86 - 0.93
Silver, oxidized | 429 | 0.04
Silver, (https://en.wikipedia.org/wiki/Silver) polished | | 0.02
Steel, oxidised | ~ 45 | 0.78
Steel, polished | | 0.07
Stainless Steel, weathered | | 0.85
Tin | 62.1 | 0.04

Πίνακας 1: Πίνακας θερμικής αγωγιμότητας-emissivity ενδεικτικών υλικών

Θερμική Ανάλυση (SimScale)

Στο τελευταίο μέρος της αναφοράς θα διεξαχθεί η θερμική ανάλυση της πλακέτας ώστε να παρατηρηθεί η ικανότητα των ψυκτρών να βγάλουν εις πέρας το ρόλο τους, αλλά και να γίνει μια μεταξύ τους σύγκριση ως προς την ικανότητας ψύξης της κάθε μίας.

Για να μπορέσουμε να πραγματοποιήσουμε την ανάλυση θα χρησιμοποιήσουμε το online πρόγραμμα SimScale.

Πριν προβούμε στις προσομοιώσεις απαιτείται να συμπληρωθούν τα παρακάτω πεδία στο SimScale.

Πιο συγκεκριμένα, ότι χρειάστηκε να συμπληρωθεί ή να αλλαχθεί στο περιβάλλον της προσομοίωσης έχει συμπεριληφθεί στην παρακάτω λίστα.

- Υλικά Στοιχείων:

❖ LM741 (OPAMP): Το σώμα του OPAMP (το πολυμερές) είναι από Epoxy. Τα pin του είναι από μόλυβδο (Lead).

❖ 2N2222 (NPN): Το σώμα του διπολικού είναι από κασσίτερο (Tin) . Τα pin του είναι από μόλυβδο (Lead).

❖ Ψύκτρες: Όλες οι ψύκτρες είναι από αλουμίνιο (Aluminium).

- Συνοριακές Συνθήκες: Για να λυθεί η διαφορική εξίσωση πρέπει το πρόβλημα να είναι καλός ορισμένο οπότε και οι τιμές της ισχύς ανά μονάδα επιφάνειας που εμφανίζεται στα pads των 2 ενεργών στοιχείων (συνοριακές επιφάνειες).

❖ LM741 (OPAMP): Από το φύλλο δεδομένων ξέρουμε ότι η μέγιστη κατανάλωση ισχύς που λαμβάνει χώρα είναι 85 mW , ενώ από το Fusion μετρήσαμε για τα 8 pads ότι το εμβαδόν τους είναι ίσο με

Area = (2 ∗ 0.145 + 1 ∗ 0.054) = 0.344 mm²

pad

Επομένως,

Power
Area =

85 mW

8 pad ∗

0.344 mm²
pad

= 30,886

W
m²

❖ 2N2222 (NPN): Από το φύλλο δεδομένων ξέρουμε ότι η μέγιστη κατανάλωση ισχύς που λαμβάνει χώρα ισούται με 500 mW , ενώ από το Fusion μετρήσαμε για τα 3 pads ότι το εμβαδόν τους είναι ίσο με

Area = 0.155 mm²
/pad

Επομένως,

Power
Area =

500 mW

3 pad ∗

0.155 mm²
pad

= 1,075,268

W
m²

Οι παραπάνω τιμές εισχωρούν στις συνοριακές συνθήκες μόνο στα pads.

- Θερμοκρασία Περιβάλλοντος & Heat Transfer Coefficient: Οι τιμές της μέγιστης ισχύς από τα φύλλα δεδομένων έχει ληφθεί για θερμοκρασία Τ = 25⁰C οπότε και αυτή επιλέχτηκε ως θερμοκρασία περιβάλλοντος για την ανάλυση που θα ακολουθήσει.

Ενώ ο συντελεστής HTC είναι ίσος με 25 W
K∗m²

- Επιφάνειες για θερμική Ανάλυση: Οι επιφάνειες που επιλέγονται για την θερμική ανάλυση είναι όλες εκτός των pads.

- Ρυθμίσεις Πλέγματος: Πέρα από τις ήδη υπάρχουσες επιλογές ,η μόνη αλλαγή έγινε στον δείκτη Fineness αναθέτοντας τον στην τιμή 8 για τις πρώτες 4 προσομοιώσεις και έπειτα στην μέγιστη τιμή 10, ώστε να επιτύχουμε μεγαλύτερη ανάλυση (καθώς έβγαζε προειδοποίηση για χαμηλή ανάλυση του πλέγματος).

Σε πρώτη φάση, θα γίνει θερμική ανάλυση των 2 στοιχείων χωρίς ψύκτρες ώστε να χρησιμοποιήσουμε τα αποτελέσματα ως αναφορά για τα αποτελέσματα με την παρουσία των ψυκτρών. Συμπληρωματικά, σε κάθε προσομοίωση πέρα από το γενικό αποτέλεσμα θα επικεντρωνόμαστε στα θερμοκρασιακά δεδομένα ενός συγκεκριμένου μέρους του στοιχείου. Ειδικότερα, για τον OpAmp και το BJT θα εστιάσουμε την προσοχή μας στο κύριο μέρος τους, όπως φαίνεται και στις παρακάτω εικόνες.

Επομένως, τώρα είμαστε σε θέση να εκτελέσουμε τις προσομοιώσεις.

Οπότε, εξάγουμε τα πρώτα αποτελέσματα (αναφοράς) που φαίνονται παρακάτω

Στην πορεία ακολουθούν 4 οι προσομοιώσεις για τον OpAmp με τις 4 διαφορετικές ψύκτρες του.

Επομένως, έχουμε:

Ψύκτρα 1

Ψύκτρα 2

Ψύκτρα 3

Ψύκτρα 4

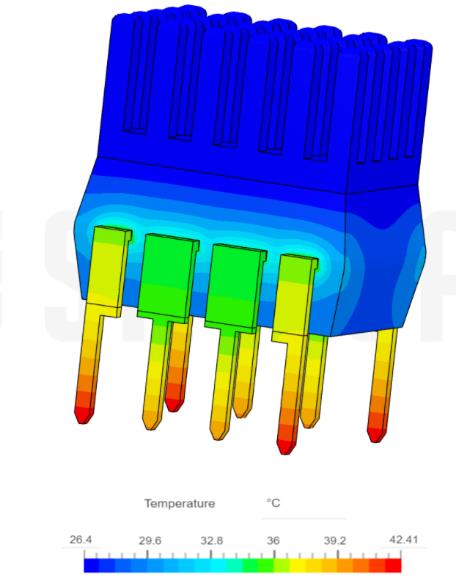
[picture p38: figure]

Για τον πιο εύκολο σχολιασμό των αποτελεσμάτων, στο παρακάτω ραβδοδιάγραμμα γίνεται η σύγκριση των θερμοκρασιών που αναπτύχθηκαν στο κύριο σώμα του OPAMP όταν δεν υπάρχει ψύξη και για τις τέσσερις διαφορετικές ψύκτρες.

Χωρίς Ψύκτρα; Ψύκτρα 1; Ψύκτρα 2; Ψύκτρα 3; Ψύκτρα 4; Μέση Θερμοκρασία (Celsius) Κύριου Μέρους OpAmp

Οπότε, έχουμε το παρακάτω αποτέλεσμα

Απόδοση(Ψ. 2) > Απόδοση(Ψ. 4) > Απόδοση(Ψ. 3) > Απόδοση(Ψ. 1)

Αξίζει να σημειωθεί ότι οι διαφορές μεταξύ των θερμοκρασιών που αναπτύχθηκαν όταν υπάρχει παρουσία ψύκτρας είναι αρκετά κοντά (διαφορά ενός δεκαδικού). Επιπρόσθετα, η θερμοκρασία χωρίς ψύξη είναι ίση με Τ = 30.34⁰C ενώ η χαμηλότερη που επιτεύχθηκε ισούται με Τ = 27.75⁰C. Βέβαια, πρέπει να τονιστεί ότι το κατώφλι της θερμοκρασίας που έχουμε είναι η Τ = 25⁰C. Κλείνοντας την πρώτη ανάλυση βλέπουμε ότι η ψύκτρα επιδρά αποτελεσματικά στην μείωση της θερμοκρασίας.

Τώρα ακολουθούν τα αποτελέσματα για τις 2 ψύκτρες του διπολικού τρανζίστορ.

Ψύκτρα 1

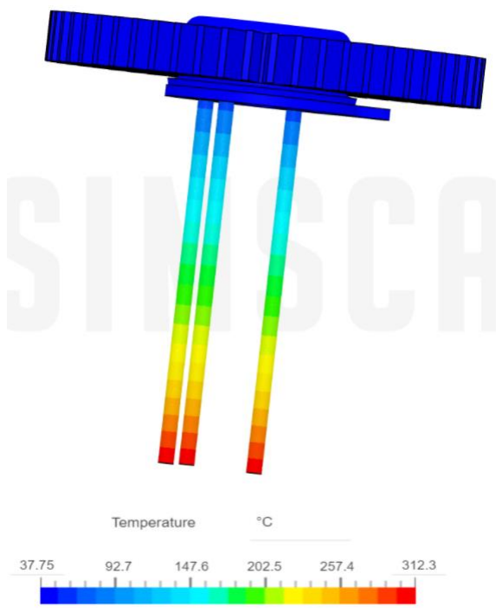
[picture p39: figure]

Ψύκτρα 2

Ομοίως με την προηγούμενη ανάλυση, θα παρουσιάσουμε το κάτωθι διάγραμμα για έναν πιο συγκεντρωτικό σχολιασμό.

Χωρίς Ψύκτρα; Ψύκτρα 1; Ψύκτρα 2; Μέση Θερμοκρασία (Celsius) Κύριου Μέρους BJT

Αρχικά παρατηρούμε ότι,

Απόδοση(Ψ. 1) ≥ Απόδοση(Ψ. 2)

Στην περίπτωση του τρανζίστορ παρατηρούμε αρχικά την εμφάνιση τριπλάσιας θερμοκρασίας όταν δεν υπάρχει ψύκτρα (σε σχέση με τον τελεστικό ενισχυτή. Γεγονός αναμενόμενο μιας και οι συνοριακές συνθήκες για το BJT ήταν πιο έντονες. Σχετικά με την ψύξη, βλέπουμε ότι οι δύο ψύκτρες επιτυγχάνουν μία μείωση κοντά στο 50% της θερμοκρασίας αποτέλεσμα αρκετά ικανοποιητικό.

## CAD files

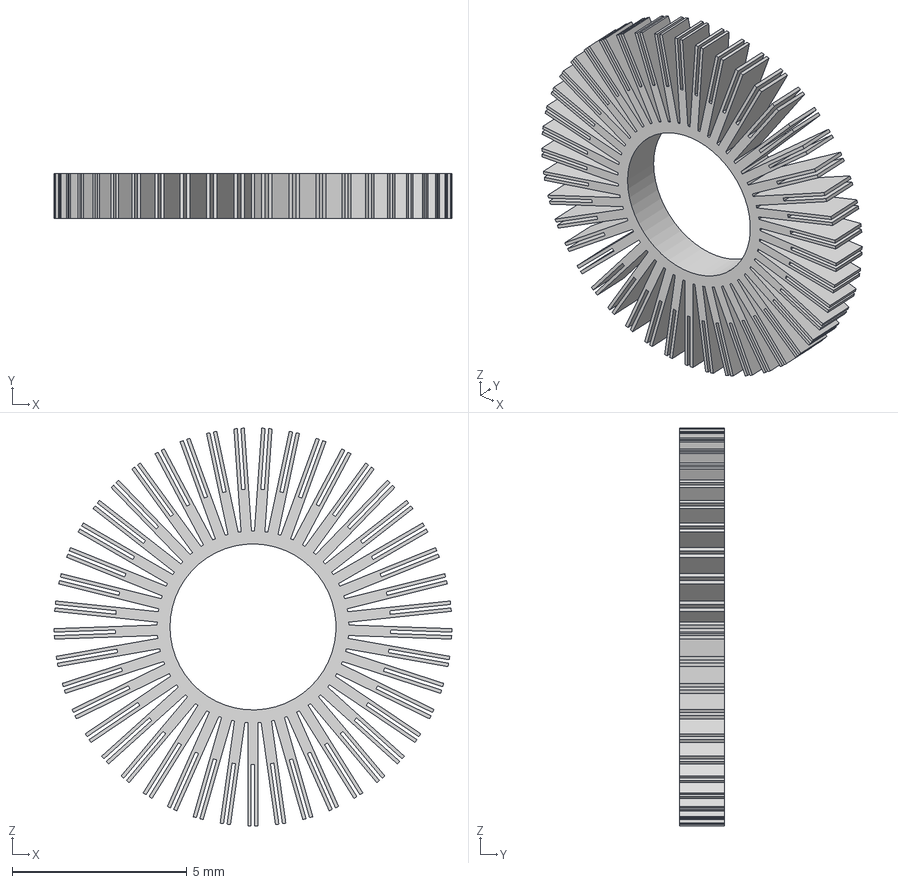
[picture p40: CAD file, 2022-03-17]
Heatsink_bjt_2n2222/bjt_HS_2.step
11.4 x 1.29 x 11.4 mm

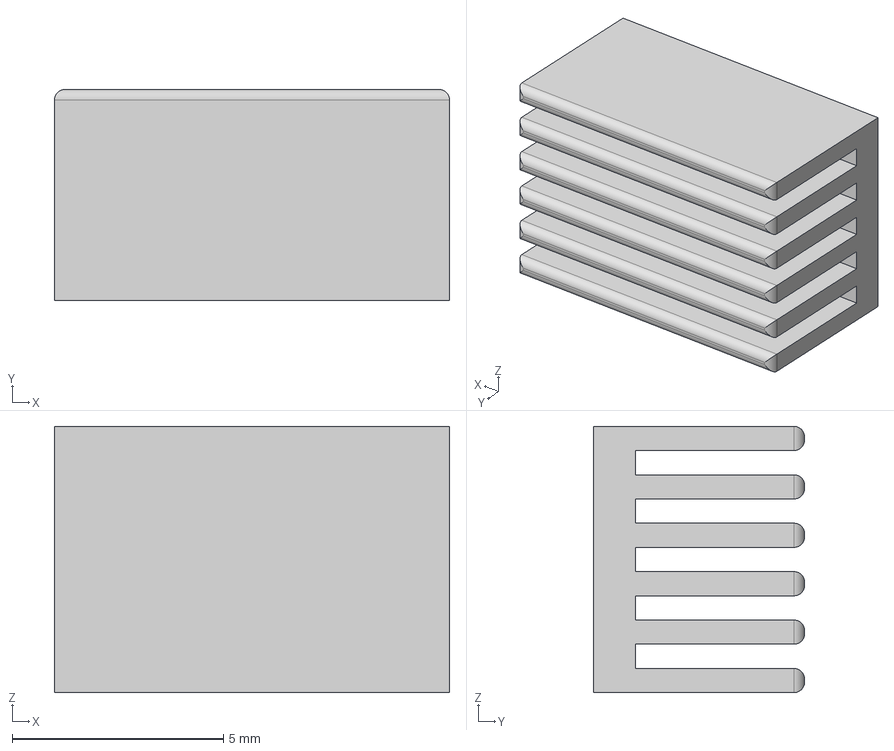
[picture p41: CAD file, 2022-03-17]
Heatsink_opamp/OPAMP_HS_4_F.step
9.35 x 5.00 x 6.30 mm

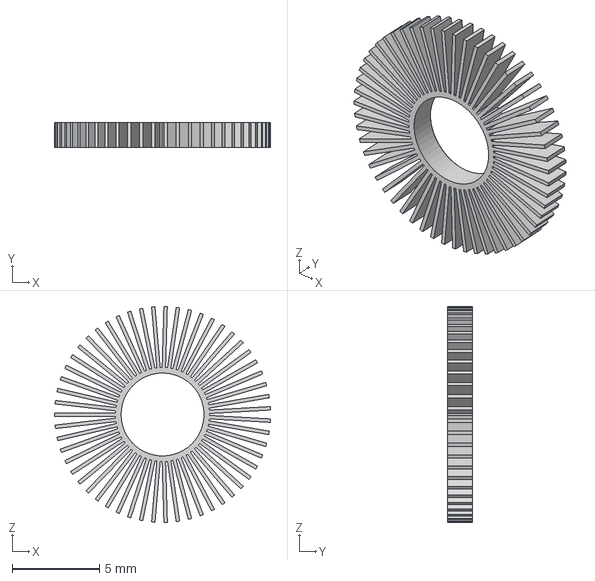
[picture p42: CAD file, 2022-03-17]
Heatsink_bjt_2n2222/bjt_HS_1_F.step
12.4 x 1.41 x 12.4 mm

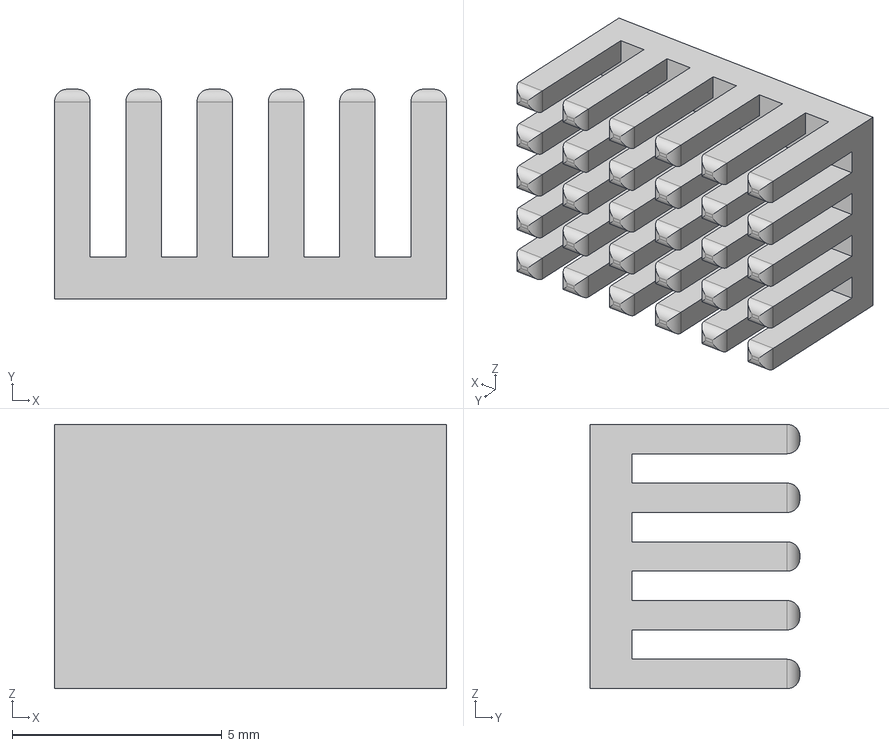
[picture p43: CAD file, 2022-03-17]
Heatsink_opamp/OPAMP_HS_2_F.step
9.35 x 5.00 x 6.30 mm

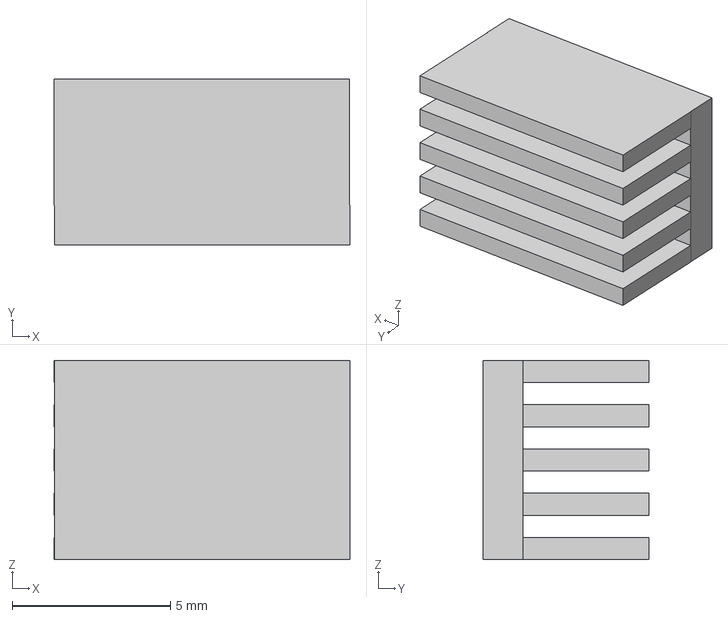
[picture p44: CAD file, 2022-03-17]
Heatsink_opamp/OPAMP_HS_1_F.step
9.36 x 5.26 x 6.30 mm

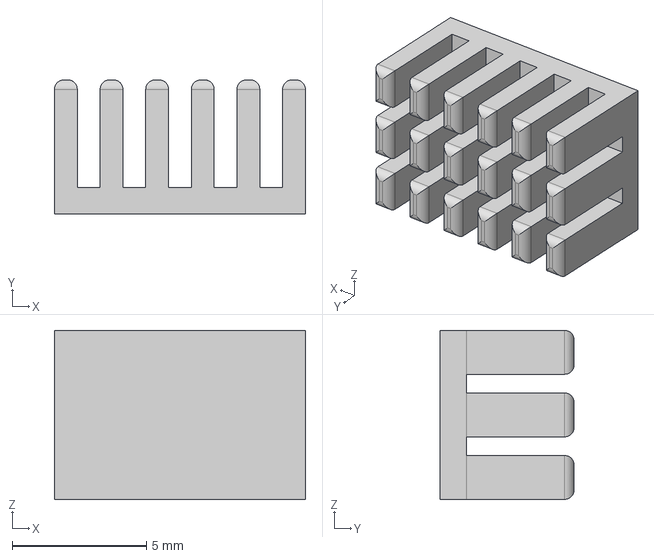
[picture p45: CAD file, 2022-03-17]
Heatsink_opamp/OPAMP_HS_3_F.step
9.35 x 5.00 x 6.30 mm
